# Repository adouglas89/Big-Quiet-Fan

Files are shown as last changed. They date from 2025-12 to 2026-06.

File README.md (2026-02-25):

# Big-Quiet-Fan
This is an axial fan with a blade that is 500 mm diameter (frame is a 550 mm square basically), that has unprecedented flow to noise ratio at pressures useful in air purification appliances, and presumably many other things.  But it's primary application is for making Extra Quiet Corsi-Rosenthal boxes (EQ-CR boxes).  Basically, they get twice the CADR with far less noise than a lasko 3733 fan on low (about 950 CFM CADR with a typical filter set, at 41 dBa noise (400 rpm), so about 9-10 dB less noise).  It's also extremely quite at lower speeds while still getting very good flow, so it's good for a bedroom to prevent allergies, for example.

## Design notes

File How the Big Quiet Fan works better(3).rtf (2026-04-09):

This document is to answer the often asked question of how/why the big quiet fan is so quiet.
● First of all the actual details of curves and polymers are not the whole story
○ The incentives surrounding the project
■ Lack of asshole boss rushing me
■ My own desire to make stuff that’s really really quiet, and do a good job to prove my abilities in this regard. I want it to be beautiful.
■ My reputation in the community and with the funding organization was an important motivating factor I guess.
■ A focus on sheer performance rather than appearance or manufacturability in the early stages. In fact sometimes noise is considered beneficial because people perceive something that’s louder to be more powerful. Obviously dispensing with that kind of pandering to ignorance is an easy way to make progress on performance. I also rejected the idea that it must be cheap. The *ratio* of cost to performance is much more important. In a way both of these and much more comes to making a wise objective function early on and allowing that to guide development efforts. The whole thing is one big optimization effort.
○ The methods I have employed including optimization, actually building prototypes, working with good efficiency are important. Both in terms of getting on with things faster and sooner and also with less money and space. With a fixed budget, higher efficiency will give a better result.
■ Prove the most uncertain stuff first. That was the blades and then the ability to print them with reasonable efficiency. Then the motor/driver comes after. That way if you have to change course you have less lost effort.
■ Obviously basic engineering fundamentals apply, like using modules that others have done a reasonable good job on wherever they are adequate.
○ “Forever modular” is useful, keeping the door open to improvement well after I thought I was done.
○ Keep orderly notes and data, I don’t think paper notes are really up to the challenge. You can’t make a spreadsheet on paper. This is important to remember and refer to what worked best, so you can mix and match the best features during the optimization process. And also if something goes wrong you can figure it out better.

I also spent some time relatively poorly, because I was working towards serial production through additive manufacture. So this whole project did take longer than it would have if I had been able to plan ahead a little more effectively. However to be fair I see supposedly much more experienced people doing very similar things with far lower efficiency. Also exploration is kind of like that, you can’t know what’s ahead, that’s part of the program.

One thing that was profoundly missing was collaborators. That would have helped a lot. Except the funding was in a way a form of collaboration.
This could have been done in some kind of community space, but you’d need some space of your own, and the freedom to run the machines overnight etc. Being able to work in my home was useful on a technical level but I think quite a problem psychologically, as you tend to have problems sleeping and waking when working and sleeping in the same relatively small house (even a full sized house, which I had for a while).

It would be a good idea to also discuss what did not work out as well, some of this will be implied, some included after.

Some people will say this is too much detail, but when you go to make a variant, it’s not going to be too much.

What is the general technique employed here?
● The general idea is to first do the best we can with simulations, then build a test rig and then try various fans with a reasonably intelligent approach (better than brute force) to see which gives the best noise and flow/pressure. To simplify things, I picked one RPM, 300, and optimized to get better results at that point. Now I’m usually using 400 rpm because it’s quiet enough at that speed, so optimizing again for that RPM might yield improvement. Unfortunately this is not actualy that easy as the only practical way to know how much noise one aspect is contributing is by eliminating it. So the motor for instance, you have to make that quiet before you can get far on the blades.
○ The optimization process involved binary searches and also looking in there with smoke etc. to see how the air was flowing around, listening to see if I could determine how the noise was being produced (easy to tell motor hum or blade buzz from the whoosh of the blades due to turbulence for instance). Then forming hypothesis, proving them and testing more.
○ I make at least 52 unique prototypes, I think. Some were not documented as they were uninteresting, like the one with the slightly defective frame that made a surprising amount of noise as a result. By this I mean I often recycled parts to make new fans, including mixing various primaries and secondaries to see what worked better. Different spacings between primary and secondary were also tried but I’m not including that in the total of 52. There must have been hundreds of exact unique combinations tried. The most important thing to document is when progress is made, but documenting everything is probably a good idea, as long as you can still find the good stuff.
○ Obviously, back the best stuff up periodically and keep an orderly workplace etc.
● It’s also useful to note that MERV-13 filters may not be the optimal at these pressures and for these configurations. There may be a significantly better filter/geometrical arrangement combo. You’d have to go back and forth testing and improving both to work your way to a better air purifier if you wanted to optimize for both 400 rpm and different filters. I used 10x merv-13 filters with the VVV in the middle (see bqap builds document).
● A primary blade that is relatively thick. It imparts pressure to the air, and also rotational motion. The pressure is directly useful, the rotational motion will be converted to pressure to some degree by the secondary. Usually it’s just about pressure. The thicker the blade disk (the cylinder around the blades) the better this works, but of course it’s a practical compromise with how large you want to let them be.
● A secondary blade, also called stator blades, which are stationary but the air is rotating relative to them, at a lower rpm however, than the primary relative to the air entering the fan.
● The primary and secondary are curved oppositely to each other, that is the spiral in the xy plane is opposite handedness. This prevents the pressure wave emanating from the primary from slamming into the secondary all of a sudden, which produces a buzzing noise that we don’t want. Many fans use struts that curve for this reason.
○ The struts on some blades are also flat and slanted to reduce their cross section in the direction which the pressure wave propagates. The secondary blades are to some degree like this automatically, although they can’t be minimal cross section of course. But they are a lot better than flat bars.
● The blade number and curves of the primary and secondary are different, the de facto rpm is different so the optimal isn’t likely to be the same.
● Spacing between the primary and secondary turned out to be important. Early prototypes did not work well as the spacing was too large.
● The thin wall on the outer edge of the blades is not strictly that helpful from a noise standpoint, I think, but it is important structurally, allowing the blades to be thinner, and thus easier to print and mold. It also prevents them from flapping around, but to be honest I never tried any variants without it so I don’t know the impact it’s having for sure. People think it reduces tip vortices, but I don’t think that’s likely to be a major factor here, that’s more of an issue at higher blade velocities.
● The spiral curvature (xy plane) and zy plane curvature of the blades,blade number for both the primary and secondary, thickness of the blade disk (thickness of the cylinders that surround the primary and secondary blades), hub diameter had to be adjusted to find something reasonably close to optimal. Diameter was fixed but in another application you might want to optimize that too.
● The grille has to be adequately far away from the primary blades, otherwise it creates noise as the pressure waves slam into it. This is why it’s not directly against the secondary, or integral with the secondary. I found it had to be a separate component, which is unfortunate as it costs more. Of course it can’t be too dense/thick elements as that would impede airflow, too. Making it further away from the primary also reduces the density it has to have, allowing air to flow through it better.
● The polymer turned out to be important. By coincidence I found some fans were quieter than others, and since I kept good notes (this is important, keep orderly notes and data) I was able to identify that it was the polymer used.
● The motor/drive solution is also something that must be done, and once again you’d think there was a good solution for this as a quiet motor is basically just a smooth running motor with sensible electronics, and there are tons of applications for that. Capstan motors, for instance, and indeed motion control in general does not benefit from vibration. Unfortunately once again everyone terminates the effort rather prematurely. Stepper motor drivers for instance, you can get ones that are specifically made to be quiet but they aren’t quiet enough, just because they didn’t do a few things that are needed. I had to do those things, making a new driver. I looked high and low for suitable motors, notably they require an adequate torque to speed ratio in a reasonably efficient operating region without being too expensive. A large motor will have a larger torque to speed ratio of course, but it costs more, it also has higher cogging usually. Cogging and other issues there is some important and useful research on but it’s a lot of work to bake the research into usable modules specific to a given motor.
○ I’m still building the super smooth and quiet motor driver for the stepper motor, but it’s looking promising.
○ With the BLDC motor, there appears to be some kind of vibration source that no change to the drive current/voltage can affect. I suspect it is flexure of the casing/the rotor backing or the stator, or both. The metal simply distorts significantly from the forces involved (any solid will distort at least a bit with any force, just a matter of how much). I am pretty sure almost any torque ripple could be solved by feeding the motor the right waveform. Unless there are some regions where the torque cannot be controlled, but I don’t think that’s the case. Hopefully this won’t happen with the stepper motor. If it does I’ll have to mount the motor in a fancy way to isolate the vibration, or we may have to tolerate a very slight motor buzz.
○ Rubber isolation is easy and important. I used orings under the screw heads etc. in the right places. This helps a lot all else being equal, to mop up that last bit of vibration/noise. They are subject to considerable forces which squishes the rubber and can allow the screw to touch the plastic if the holes are not large enough etc. (3.5 mm drill size is good, not 3.2)

It’s worth noting that it’s probably possible to improve performance slightly further by further adjusting the curves and blade number, thickness of the blade disk, hub diameter etc.I am not immune to the reality which probably led most other fans to not be very good, which is that you have to get on with actually making them at some point, and there is not really that much good reason to exceed the requirements set. That would be ASHRAE 241 for the amount of clean air we need in a classroom and other buildings,and ANSI S12.60, for noise in classrooms (hospital wards and other spaces have similar standards which have mostly similar values anyway). This fan can already be used to make an appliance that can do that with only one fan, while everything else is a long way away from that.

Because things are modular I could change things later to pursue this improvement, if/when there is a good enough reason and funding.

What did not work very well?
● The rings similar to the outermost wall, I had some in the middle regions too, and they added a lot of noise. They did improve the flow/pressure to rpm ratio, though, as predicted by simulations. I noticed from the simulations that the pressure/flow was better in the regions close to these rings, so that is why I added them. That was correct. But the simulation did not show the increased noise.
● I tried using a tpu/nylon blend to increase damping, just for the primary, but it made no difference so I went back to the previous approach. I thought it was going to help as the difference in damping between some rigid filaments did help. It might help for the secondary more, but it’s a little too floppy, it was 72D durometer. 100D might work ok but I couldn’t get any. You can have high damping while still having high stiffness, there is nothing stopping that. It’s just that TPU has good damping and is usually used in elastomers. There are some papers that describe filaments with unusually high damping but you can’t buy the filament of course.

Things I did not try
● Multiple rotors, separated by stators to reduce the rotational velocity of the air. This would increase cost and it actually can get complicated because the bearings can make noises etc. which can be solved but it takes more time and the per unit cost would go up. A single primary and secondary is a reasonable compromise.
● One thing that has some potential is airfoil shaped blades, i.e. the back of the blade has a different curvature than the front. This would be easy to do with printing but it makes the blade thick so with molding you’d end up with heavy blades and using a lot of plastic. Contraction could also be a serious problem. You could try to make it in pieces and assemble them or something. But that’s expensive. For this reason I did not explore airfoil shapes much. I did simulate some and it didn't seem to help much so I didn’t pursue it.
Things that probably don’t matter much
● Some people think the ridges on the sides from the printing must have an impact that is detrimental. I think this is unlikely due to the boundary layer, especially.
● I tried slanting the outer wall a little but it made basically no difference. I may do this again when designing for manufacture as it should make removal from the mold easier.

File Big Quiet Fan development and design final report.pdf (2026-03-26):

# Final report for grant A42, design of the

Big Quiet Fan.

# A fan to greatly outperform the existing fan solutions

for air purifiers.

The project went remarkably well and most of the progress was made in a very short time. Later stages did take longer than I would like, mostly due to waiting on others which tends to be extremely time consuming in the world of manufacturing for some reason.

Extremely good performance has been achieved. Energy efficiency, noise to flow/pressure relationship and even cost of manufacture are all very very good now. Progress was repeatedly made in a less than expected way. Several times I thought I was basically done but was able to make progress on core metrics, notably the CADR to noise ratio when fitted with a typical filter set (about 1000 CFM CADR at 9 pascals of pressure, usually 4 1x25x20 MERV-13 Filtrete filters plus a 20 by 20 by 1 inch one on the bottom of the box, with legs).

I discovered several basic techniques to improve performance of the blades, which can be applied to many other fans in the future:
- Increase the depth of the blades to increase pre-swirl and increase pressure/flow generation of the first blades (what I call the primary blades).
- Use a similar stator (the secondary, I call it), which uses the pre-swirl to boost flow/pressure. This is usually called a straightener, and it does straighten the airflow, but it’s purpose is not actually to do so. I realized it’s basically a fan blade, except the air rotates relative to the blades while the blades stay still.
- Again the stator should be relatively deep
- The curvature of the blades needs to be optimized for any given fan, which I have done here. The optimal in this case appears to be a sort of spiral in the plane perpendicular to the axis of rotation, and a parabolic curve in the other plane.
- The number of blades for both primary and secondary also needs to be optimized, this of course dictates spacing.
- The spirals of the primary and secondary should be of opposite handedness, to eliminate buzzing noise. Buzzing noises can still arise depending on the details of the geometry, I was able to find some combination that practically eliminates any buzz.
- As usual the root of the blades has a different average angle of attack than the tip, usually higher.
- An outermost cylindrical wall allows the blades to be thin and light, and any geometry desired as their stiffness is not a problem. It may help with the turbulence at the tips but

I don’t actually know because it is probably at least harmless and useful to improve the mechanical properties of the blades, so I never tried without it.
- Use a high damping plastic/material for the secondary to reduce noise, this helps a surprising amount.
The process of optimizing the curves and number of blades etc. is basically the hard part. I used simulations but due to the large size of the object and the detail required that didn’t give very good accuracy. The limits of the software I was using were too severe, but certainly it’s fundamentally possible to get better results. In general the software can tell the turbulence energy which should correlate strongly with noise.

One thing that has potential but I did not try much is to change the curvature of the front and back of the blades. In general, I use a thin sheet of material, the curve being the same on both sides. In general an airfoil works better with a different curve on the back than the front, however this would be very heavy and consume more plastic when molded, it also takes far longer to print. I did experiment a bit and it seemed unpromising.

It is probably possible to slightly increase performance by maybe 10 percent, but progress really slowed down and that would be a bit costly. I pretty much hit the budgeted $ on the head so I feel I struck a good compromise.

In general, I measured the pressure inside the filter box while testing a wide range of primaries and secondaries, and each promising combination of the two. I did more than 65 tests of unique combinations. I also poked around visualizing the flow with fog, and hypothesized how promising ways to improve things, combining the best features.

One feature that was promising in simulation but did not help in reality was the use of vertical cylindrical walls that divide up the blades, allowing the blade spacing to be optimized in the different regions. The thing is the blades are moving through the air more slowly in the middle than the edge so it would stand to reason the optimal geometry and spacing would be different there. It also interrupts the undesired radial flow of the air due to centrifugal force. Although this type of feature did improve the rpm to pressure/flow relationship, they increased noise unexpectedly so were dispensed with.

I realized several things:
- Most of the buzzing noise is from the pressure wave hitting the secondary. The opposite handed spirals is the best way to solve this as it also works well in other ways. However optimization of the curves is needed to really polish it off.
- The spacing between the primary and secondary is also very important. In this fan it should be between 3-4 mm. A bit outside that range isn’t a big deal, but it does adversely affect noise/flow/pressure relationship.
- Bearing noise is actually significant and Z4 bearings should be used.

I also found a clever solution for the motor drive system which has many other applications where extremely smooth and quiet motion is desired, especially with a high torque to speed ratio at a low cost:
- The stepper motors were fundamentally promising as they have good torque/speed ratio and are low cost and easy to get. I was actually able to source a hall effect sensor equipped gimbal motor which they say could be supplied for $45 USD, which is highly unusual for such motors of such size and properties, a very good deal. However that came too late and I never even tested it. A suitable stepper is about $8 and the supply is inherently more reliable, so it’s better to use that if you can.
- I knew that sine wave drive tends to work pretty well, audible ring and other noises typically involved with stepper motors can be eliminated, the only remaining vibration would be cogging. The other challenge was commutation while keeping cost low.
- I was able to re-invent synchronous drive basically, almost by accident. It turns out if you just ramp the voltage with RPM that actually works great to drive the motor, the current and torque is automatically regulated within a fairly wide range due to the way the back emf changes with the so called torque angle (when the motor is loaded more, back emf goes down allowing more current, increasing torque to match the load).
- However I found the system oscillated too much, leading to step loss. I was able to solve this with damping using TPU, a flywheel made of TPU with enough bolts around it’s periphery for mass was sufficient.
- The last bit of vibration was dealt with by isolation, using a flexible coupler. It was difficult to deal with the creep set etc. however I was able to find a solution.
- The noise from even the Z4 bearings (quietest you can get) had to be isolated with a small hard TPU cushion (72D) around the bearings, but this is cheap and works well.

Unfortunately this whole system does imply increased costs over a bare stepper motor directly driving the blades, but not much, just some plastic and rubber parts and a couple bearings, and the shaft. The parts can all be printed or molded easily.

I did not try multiple rotors, perhaps on the same shaft. That has potential, it increases size but could be sensible. That would be the next major pattern to employ to further increase the noise/cadr ratio, I think. However it increases size and complexity and thus cost. This system is quite close to any ordinary fan, in its simplicity,and I think it’s rare you would have a compelling need for better CADR/noise ratio. You can always just use twice as many air purifiers, in a pinch. I think this is a good compromise.

Driving the fan blades with the motor directly does actually work, the vibrations are damped enough, but you get a buzzing noise. I tried quite extensively to eliminate this buzzing noise through firmware optimization. Theoretically I thought the cogging could be eliminated by superimposing the waveform 180 degrees out of phase, causing a torque ripple that cancels out the cogging or other torque ripple. I built a system that was able to measure torque ripple normatively and used a global optimizer to adjust the waveform, searching for any waveform that would help and improving on it. The system was good, if I imposed a torque ripple it was able to quickly find the right waveform to cancel it out, however for some reason that I still do not understand it was never able to make meaningful reductions in the torque ripple that the stepper motor exhibited with pure sine wave drive. It may be that there were oscillations in the electrical-mechanical system combined which were dynamic in origin. However I did actually test for this by putting damping in in the electrical line and it didn’t seem like it. It’s possible a damping flywheel on the back of a dual shaft stepper with the blades directly mounted to the motor would work, but I don’t think so. I tried a rubber coupler on the blades which should have a similar effect and it hardly helped.

I have designed a drive system PCB which is applicable to other applications and can easily be reprogrammed. It uses relatively common and low cost parts. It is fairly refined, I got the pro layout service and have gone through several prototypes. Extra pins are broken out for auxiliary use etc. The Arduino program is also of course published and can be adapted to other scenarios.

Budget:
Total budget was $50,000 USD for the design and development, including all materials, equipment, premises and labor. Most of this was expended and the remainder has been woven into future grants.
| cad | usd
labor rate | 35
| CAD | USD
labor cost | 44800 | 32463.76812
Parts/equipment /materials | 15831 | 11471.73913
premises | 1800 | 1304.347826
With labor | 62431 | 45239.85507

Estimated impact
This part of the road has now been well paved for far superior noise/cadr ratio air purifiers for
millions or even billions of people around the globe. To have not undertaken such a research project would have been absurd, given the number of fans and air purifiers that are needed across the globe in the coming years.

I would argue it is a bit wacky to only have one person on a relatively tight budget doing this, given the apparent potential. It would be great to build a simulation system and really make something completely optimal. However I would be surprised if that led to even a 10% improvement in CADR to noise ratio.

This fan as it stands really is pretty good. I can turn it up to 400 rpm (1030 cfm CADR measured) and work in my apartment right next to it without irritation, in fact the sheer amount it moves around, causing quite a draft is the most annoying part of leaving it on like that. If I turn it down it is inaudible at normal distances even with 36 dBa background noise, allowing tremendous CADR while sleeping.

The techniques could also be applied to other smaller format air purifiers. There are companies that make 250 mm PC fans for instance, it would be a good idea to use these tricks in that context, especially combined with their low cost approach to the motor.

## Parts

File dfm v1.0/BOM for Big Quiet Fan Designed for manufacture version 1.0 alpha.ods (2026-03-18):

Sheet: bom
group | part or material | sub group | specs | number | cost each CAD | cost each USD | labor minutes | total cost | grams plastic (estimate) | mold or tooling cost | notes | supplier
high damping plastic parts | secondary/frame |  |  | 1 |  | 9.5 |  | 9.5 | 1300
 | primary |  |  | 1 |  | 7 |  | 7 | 750
 | grille |  |  | 1 |  | 4 |  | 4 | 300
 |  |  |  |  |  |  |  | 0
any hard plastic parts |  |  |  |  |  |  |  | 0
 | electronics cover |  |  | 1 |  | 2 |  | 2 | 90
 | motor mount |  |  | 1 |  | 3 |  | 3 | 300
 | shaft clamp |  |  | 1 |  | 2 |  | 2
 | motor cover |  |  | 1 |  | 1.5 |  | 1.5
Shore 95A TPU |  |  |  |  |  |  |  | 0
 | Motor mount flexure |  |  | 1 |  | 2.5 |  | 2.5
 | flywheel |  |  | 1 |  | 2 |  | 2
 | bearing cushion |  |  | 2 |  | 0.25 |  | 0.5
 | shaft spacer motor side |  |  | 1 |  | 0.25 |  | 0.25
 | shaft spacer blade side |  |  | 1 |  | 0.25 |  | 0.25 |  |  | haven't tried it with 95 A yet, I used 72D in prototyping, any hard plastic is probably fine actualy but need to test it, even small squeaking sounds can be a problem.
Shore 85A TPU |  |  |  |  |  |  |  | 0
 | coupler rubber part |  |  | 1 |  | 0.4 |  | 0.4
rubber |  |  |  |  |  |  |  | 0
 | orings are used in the prototypes to compensate for poor perpendicularity, this should not be needed in mass production. |  |  |  |  |  |  | 0 |  |  | Not clear yet if orings on the shaft clamp to primary interface are beneficial for isolating bearing noise, experiment needed. Probably not.
electronics/electrical |  |  |  |  |  |  |  | 0
 | electronics board/driver |  | 2 phase stepper driver, sine wave, with voltage ramping, stall/overload detection, motion detect on startup, acceleration, serial interface, pwm in and tach out | 1 |  | 16 |  | 16
 | power supply |  | 24 volt 2 amp, ul listed, with integral short circuit/overcurrent protection, 5.5 mm jack barrel ground I think | 1 |  | 6 |  | 6
 | 6 pin 3.81 mm pitch 2edgk connector, pluggable,male |  |  | 1 |  | 1 |  | 1 |  |  | for motor wires to board interface
 | thermal fuse |  | trips at 72 degrees C is good. 4 amps min. | 1 |  | 1 |  | 1
 | wire for thermal fuse |  | should be red to indicate positive power side | 1 |  | 1.5 |  | 1.5
screws |  |  |  |  |  |  |  | 0
 | M3 self tapping 12 mm long 2.5 mm hex socket head | For motor flexure mounting | alloy (black finish is fine) | 8 |  | 0.05 |  | 0.4
 |  | for grille mounting | alloy (black finish is fine) | 8 |  | 0.05 |  | 0.4
 | M3 8 mm self tapping screws 2.5 mm head | for primary to shaft clamp interface |  | 3 |  | 0.05 |  | 0.15
 | M3 self tapping 20 mm screws , 2.5 mm hex socket head | for motor mount to secondary interface |  | 3 |  | 0.05 |  | 0.15
 | M3 8 mm self tapping screws 2.5 mm head | electronics cover screws |  |  |  | 0.05 |  | 0
 | M2 self tapping screws 8 mm long, hex socket head 1.5 mm socket | for mounting electronic board | alloy (black finish is fine) | 4 |  | 0.05 |  | 0.2
 | M5 bolts for shaft clamp (lenght?) Hex socket |  | stainless or alloy, regular thread | 2 |  | 0.3 |  | 0.6
 | M5 nuts |  | stainless or alloy regular thread | 2 |  | 0.15 |  | 0.3
other |  |  |  |  |  |  |  | 0
 | shaft |  | 68 mm long is ideal, 70 is fine. | 1 |  | 2 |  | 2
 | shaft retention clamp |  | 8 mm id shaft clamp to ensure the primary cannot slowly slide off if friction is not adequate at high power. | 1 |  | 3 |  | 3 |  |  | this is probably optional and could be omitted, if so the shaft can be reduced in lenght by about 10 mm
 | bearings 8 mm ID OD? Thickness? |  | Should be Z4 noise at least I think that's what I have, the precision I forget but I'm pretty sure the ones I have are actually P6. So top notch bearings on both counts basically | 2 |  | 0.25 |  | 0.5 |  |  | no idea what abec that is.
 | Motor |  | Nema 23 2Nm or more, some make more vibrational noise than others, it has to be one of the quiet ones | 1 |  | 11 |  | 11 |  |  | rattmotor ones worked but have a high defect rate. The only one I know for sure that works right now is model number 23Hs8430B 3A, which is a dual shaft model so not ideal.
 | 3 jaw spider coupler |  | should be a 3 jaw one, you have to watch. 8 mm ID. | 1 |  | 3 |  | 3
assembly jigs and tools and mateials |  |  |  |  |  |  |  | 0
 | motor flexure positioning jig |  |  |  |  |  |  | 0 |  |  | simple printed object to position the motor mount flexure on the motor in the ideal spot easily
 | screw drivers |  |  |  |  |  |  | 0
 | E6000 glue |  |  | 1 |  | 0.1 |  | 0.1 |  |  | to glue the moto rmount flexure to the motor, this is optional but probably advisable.
total |  |  |  |  |  |  |  | 82.2

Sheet: labor and other costs
 | assembly process actions |  | labor minutes | notes
per unit
 | cut wire for thermal fuse |  | 1
 | solder wire to thermal fuse (be very careful not to overheat it), test it to ensure not broken by soldering, then glue to the motor ith e6000. Should go on back of motor to not interfere with flexure |  | 2 | might need to attach heatsink (spring loaded pliers basically/latching pliers)
 | put flexure on motor inright position and glue flexure to motor |  | 2
 | put bolts on flywheel |  | 3
 | add clamp bolt to flywheel |  | 1
 | put flywheel on motor |  | 1
 | attach spider coupler motor side |  | 0.5
 | attach spider coupler shaft side |  | 0.5
 | add shaft spacer to shafr behind spider coupler |  | 0.5
 | add rubber peice to spider coupler |  | 1
 | add bearing cushions and bearings to motor mount |  | 1
 | insert motor/flywheel/shaft assembly into motor mount |  | 1
 | install motor mount in secondary |  | 2
 | attach shaft clamp to primary |  | 1
 | put bolts and nuts on shaft clamp |  | 0.5
 | put shaft spacer on shaft |  | 0.5
 | connect shaft clamp/primary to shaft, press slightly to ensure no axial play |  | 1
 | add shaft clamp to ensure retention. |  | 0.5
 | add electronics board |  | 1
 | wire the connector for the motor-board connection |  | 4
 | test it |  | 10
 | any corrections. Noise must be acceptable. For early units, check stall detection is working |  | 5
 | add the electronics cover |  | 1
 | add motor cover on back |  | 1
 | packaging |  | 10
 | coordination, management, restocking etc. |  | 5
 | total labor minutes |  | 57
 | labor rate usd per hour | 25
 | cost for labor |  | 23.75
 | premises |  | 4
 | electricity, other random stuff |  | 2
 | sum of all labor, parts and costs. |  | 111.95

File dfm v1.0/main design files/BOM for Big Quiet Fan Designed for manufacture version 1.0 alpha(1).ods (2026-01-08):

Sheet: bom
group | part or material | sub group | specs | number | cost each CAD | cost each cad | labor minutes | line cost USD | grams plastic (estimate) | mold or tooling cost | notes | supplier
high damping plastic parts | secondary/frame |  |  | 1 |  | 11 |  | 11 | 1300 |  | includes shipping
 | primary |  |  | 1 |  | 10 |  | 10 | 750 |  | includes shipping
 | grille |  |  | 1 |  | 5 |  | 5 | 300 |  | includes shipping
any hard plastic parts, probably print farmed
 | electronics cover |  |  | 1 |  | 3 |  | 3 | 90
 | motor mount |  |  | 1 |  | 4 |  | 4 | 300
 | shaft clamp |  |  | 1 |  | 2 |  | 2
 | motor cover |  |  | 1 |  | 2 |  | 2
Shore 95A TPU
 | coupler blade side |  |  |  |  | 2
 | flywheel |  |  | 1 |  | 2 |  | 2
 | bearing cushion |  |  | 2 |  | 0.25 |  | 0.5 |  |  | might want harder tpu to reduce sag, try it
 | shaft spacer motor side |  |  | 1 |  | 0.25 |  | 0.25 |  |  | might want harde tpu
 | shaft spacer blade side |  |  | 1 |  | 0.25 |  | 0.25 |  |  | might want harde tpu
Shore 85A TPU
 | Motor mount flexure |  |  | 1 |  | 2.5 |  | 2.5
rubber
 | orings are used in the prototypes to compensate for poor perpendicularity, may be able to eliminate this with adjustment, the process of manually adjusting things is also a pain so that would be good |  |  | 3 |  | 0.05 |  | 0.15
 | same orings are used on the rubber coupler in two areas |  |  | 2 |  | 0.05 |  | 0.1
electronics/electrical
 | electronics board/driver |  | 2 phase stepper driver, sine wave, with voltage ramping, stall/overload detection, motion detect on startup, acceleration, serial interface, pwm in and tach out | 1 |  | 16 |  | 16
 | power supply |  | 24 volt 2 amp, ul listed, with integral short circuit/overcurrent protection, 5.5 mm jack barrel ground I think | 1 |  | 6 |  | 6
 | 6 pin 3.81 mm pitch 2edgk connector, pluggable,male |  |  | 1 |  | 1 |  | 1 |  |  | for motor wires to board interface
 | thermal fuse |  | trips at 72 degrees C is good. 4 amps min. | 1 |  | 1 |  | 1
 | wire for thermal fuse |  | should be red or yellow to indicate positive power side | 1 |  | 1.5 |  | 1.5
 | any additional wire needed, usually to extend the stepper motor wires |  |  |  |  |  |  | 1
screws
 | M3 self tapping 8 mm long 2.5 mm hex socket head | For motor flexure mounting | alloy (black finish is fine) | 8 |  | 0.05 |  | 0.4
 | 8x M3 12 mm screws | for grille mounting | alloy (black finish is fine) | 8 |  | 0.05 |  | 0.4
 | M3 8 mm self tapping screws 2.5 mm head | for primary to shaft clamp interface |  | 3 |  | 0.05 |  | 0.15
 | M3 self tapping 20 mm screws , 2.5 mm hex socket head | for motor mount to secondary interface |  | 3 |  | 0.05 |  | 0.15
 | M3 self tapping 20 mm screws , 2.5 mm hex socket head | for motor cover |  | 4 |  | 0.05 |  | 0.2
 | M3 8 mm self tapping screws 2.5 mm head | electronics cover screws |  | 3 |  | 0.05 |  | 0.15
 | M2 self tapping screws 8 mm long, hex socket head 1.5 mm socket | for mounting electronic board | alloy (black finish is fine) | 4 |  | 0.05 |  | 0.2
 | M6 bolts for flywheel |  | alloy (black finish is fine) 10 mm length | 10 |  | 0.5 |  | 5 |  |  | I don't know why they are so expensive but they are.
 | m6 nuts for flywheel |  |  | 10 |  | 0.1 |  | 1
 | M6 bolts for the motor side flywheel clamp |  | M6 30 mm IIRC, check length again. | 2 |  | 0.05 |  | 0.1
 | M6 nuts |  |  | 2 |  | 0.05 |  | 0.1
 | M4 bolts for the bladeside shaft coupler |  | alloy (black) 30 mm IIRC, check that | 2 |  | 0.05 |  | 0.1
 | M4 nuts |  |  | 2 |  | 0.05 |  | 0.1
 | M4 washers |  |  | 4 |  | 0.05 |  | 0.2
 | M5 bolts for shaft clamp (lenght?) Hex socket |  | stainless or alloy, regular thread | 2 |  | 0.3 |  | 0.6
 | M5 nuts |  | stainless or alloy regular thread | 2 |  | 0.15 |  | 0.3
other |  |  |  |  |  |  |  | 0
 | shaft |  | 68 mm long is ideal, 70 is fine. 8 mm od, shaft tolerance of couse | 1 |  | 2 |  | 2
 | bearings 8 mm ID OD? Thickness? |  | Should be Z4 noise at least I think that's what I have, the precision I forget but I'm pretty sure the ones I have are actually P6. So top notch bearings on both counts basically | 2 |  | 0.25 |  | 0.5 |  |  | no idea what abec that is. We might want to up the outer diameter and thickness, the ID is good as is though.
 | Motor |  | Nema 23 2Nm or more, some make more vibrational noise than others, it has to be one of the quiet ones | 1 |  | 13 |  | 13 |  |  | rattmotor ones worked but have a high defect rate. The only one I know for sure that works right now is model number 23Hs8430B 3A, which is a dual shaft model so not ideal.
 | 4 jaw spider coupler |  | should be a 4 jaw one, you have to watch. 8 mm ID. 25 mm od. what was the overall length again? | 0.5 |  | 3 |  | 1.5 |  |  | that's 2 prongs per half. We only use half of one.
assembly jigs and tools and mateials |  |  |  |  |  |  |  | 0
 | motor flexure positioning jig |  |  |  |  |  |  | 0 |  |  | simple printed object to position the motor mount flexure on the motor in the ideal spot easily
 | screw drivers |  |  |  |  |  |  | 0
 | E6000 glue |  |  | 1 |  | 0.1 |  | 0.1 |  |  | to glue the moto rmount flexure to the motor, this is optional but probably advisable.
 | solder
total |  |  |  |  |  |  |  | 95.5

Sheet: labor and other costs
 | assembly process actions |  | labor minutes | notes
per unit
 | cut wire for thermal fuse |  | 1
 | solder wire to thermal fuse (be very careful not to overheat it), test it to ensure not broken by soldering, then glue to the motor ith e6000. Should go on back of motor to not interfere with flexure |  | 2 | might need to attach heatsink (spring loaded pliers basically/latching pliers)
 | put flexure on motor inright position and glue flexure to motor |  | 2
 | put bolts on flywheel |  | 3
 | add clamp bolt to flywheel |  | 1
 | put flywheel on motor |  | 1
 | attach spider coupler motor side |  | 0.5
 | add shaft spacer to shafr behind spider coupler |  | 0.5
 | add rubber peice to spider coupler |  | 1
 | add bearing cushions and bearings to motor mount |  | 1
 | insert motor/flywheel/shaft assembly into motor mount |  | 1
 | install motor mount in secondary |  | 2
 | attach shaft clamp to primary |  | 1
 | put bolts and nuts on shaft clamp |  | 0.5
 | put shaft spacer on shaft |  | 0.5
 | connect shaft clamp/primary to shaft, press slightly to ensure no axial play |  | 1
 | add shaft clamp to ensure retention. |  | 0.5
 | add electronics board |  | 1
 | wire the connector for the motor-board connection |  | 4
 | test it |  | 5
 | any corrections. Noise must be acceptable. For early units, check stall detection is working |  | 5
 | add the electronics cover |  | 1
 | add motor cover on back |  | 1
 | packaging |  | 10
 | coordination, management, restocking etc. |  | 5
printing
 | all printing |  | 15
 | post processing |  | 10
 | total labor minutes |  | 76.5
 | labor rate cad per hour | 25
 | cost for labor |  | 31.875
 | premises |  | 4
 | electricity, other random stuff |  | 2
 | sum of all labor, parts and costs. cad |  | 133.375

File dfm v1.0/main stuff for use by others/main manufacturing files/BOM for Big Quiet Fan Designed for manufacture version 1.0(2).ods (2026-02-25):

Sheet: bom fully moldable
group | part or material | sub group | other specs | number | cost each cad | labor minutes | line cost cad | usd | grams plastic (estimate) | mold or tooling cost | notes | supplier | part number
high damping plastic parts | secondary/frame |  |  | 1 | 7 |  | 7 |  | 1300 |  | includes shipping | molded by injection molder, who is not clear yet
 | primary |  |  | 1 | 7 |  | 7 |  | 750 |  | includes shipping | molded by injection molder, who is not clear yet
 | grille |  |  | 1 | 5 |  | 5 |  | 300 |  | includes shipping | molded by injection molder, who is not clear yet
any hard plastic parts, probably print farmed
 | electronics cover |  |  | 1 | 1 |  | 1 |  | 90 |  |  | molded by injection molder, who is not clear yet
 | motor mount |  |  | 1 | 1 |  | 1 |  | 300 |  |  | molded by injection molder, who is not clear yet
 | motor cover |  |  | 1 | 1 |  | 1 |  |  |  |  | molded by injection molder, who is not clear yet
Shore 95A TPU
 | coupler blade side |  |  | 1 | 1 |  | 1 |  |  |  |  | molded by injection molder, who is not clear yet
 | flywheel |  |  | 1 | 1 |  | 1 |  |  |  |  | molded by injection molder, who is not clear yet
 | shaft spacer motor side |  |  | 1 | 0.1 |  | 0.1 |  |  |  | might want harde tpu | molded by injection molder, who is not clear yet
 | shaft spacer blade side |  |  | 2 | 0.1 |  | 0.2 |  |  |  | might want harde tpu | molded by injection molder, who is not clear yet
shore 72D TPU
 | bearing cushion |  |  | 2 | 0.1 |  | 0.2 |  |  |  | might want harder tpu to reduce sag, try it | molded by injection molder, who is not clear yet
Shore 85A TPU
 | Motor mount flexure |  |  | 1 | 1 |  | 1 |  |  |  |  | molded by injection molder, who is not clear yet
other rubber
 | orings are used in the prototypes to compensate for poor perpendicularity, may be able to eliminate this with adjustment, the process of manually adjusting things is also a pain so that would be good |  |  | 3 | 0.05 |  | 0.15 |  |  |  |  | any
 | same orings are used on the rubber coupler under the arms, this may be optional |  |  | 2 | 0.05 |  | 0.1 |  |  |  |  | any
electronics/electrical
 | electronics board/driver |  | 2 phase stepper driver, sine wave, with voltage ramping, stall/overload/miswiring detection, motion detect on startup, acceleration, serial interface, pwm in and tach out | 1 | 20 |  | 20 |  |  |  |  | custom board, jlcbpcb works fine
 | power supply |  | 24 volt 2 amp, ul listed, with integral short circuit/overcurrent protection, 5.5 mm jack barrel ground I think | 1 | 6 |  | 6 |  |  |  |  | any
 | 6 pin 3.81 mm pitch 2edgk connector, pluggable,male |  |  | 1 | 1 |  | 1 |  |  |  | for motor wires to board interface
 | thermal fuse |  | trips at 72 degrees C is good. 4 amps min. this one is good for 10 amp | 1 | 1 |  | 1 |  |  |  | I don't think we really need the thermal fuse but let's include it for now for redundant safety | Cantherm is the manufacturer, digikey sells it | SDF DF077S
 | wire for thermal fuse |  | should be red or yellow to indicate positive power side | 1 | 1.5 |  | 1.5 |  |  |  |  | any
 | knob for potentiometer |  |  | 1 | 0.2 |  | 0.2 |  |  |  |  | any
 | power supply pigtail |  | 30 long is good, 5.5 mm jack | 1 | 2 |  | 2 |  |  |  |  | any
screws
 | M3 self tapping 8 mm long 2.5 mm hex socket head | For motor flexure mounting | alloy (black finish is fine) | 8 | 0.05 |  | 0.4 |  |  |  |  | any
 | 8x M3 12 mm screws | for grille mounting | alloy (black finish is fine) | 8 | 0.05 |  | 0.4 |  |  |  |  | any
 | M3 8 mm self tapping screws 2.5 mm head | for primary to shaft clamp interface |  | 3 | 0.05 |  | 0.15 |  |  |  |  | any
 |  | for output grille |  | 8 | 0.05 |  | 0.4 |  |  |  |  | any
 | M3 8 mm self tapping flat end screws | for intake grille |  | 8 | 0.05 |  | 0.4 |  |  |  |  | any
 | M3 self tapping 20 mm screws , 2.5 mm hex socket head | for motor mount to secondary interface |  | 3 | 0.05 |  | 0.15 |  |  |  |  | any
 | M3 self tapping 20 mm screws , 2.5 mm hex socket head | for motor cover |  | 4 | 0.05 |  | 0.2 |  |  |  |  | any
 | M3 8 mm self tapping screws 2.5 mm head | electronics cover screws |  | 3 | 0.05 |  | 0.15 |  |  |  |  | any
 | M2 self tapping screws 8 mm long, hex socket head 1.5 mm socket | for mounting electronic board | alloy (black finish is fine) | 3 | 0.05 |  | 0.15 |  |  |  |  | any
 | M6 bolts for flywheel |  | alloy (black finish is fine) 10 mm length | 8 | 0.5 |  | 4 |  |  |  | I don't know why they are so expensive but they are. | any
 | m6 nuts for flywheel |  | alloy (black finish is fine) | 8 | 0.1 |  | 0.8 |  |  |  |  | any
 | M6 bolts for the motor side flywheel clamp |  | M6 30 mm IIRC, check length again. | 2 | 0.05 |  | 0.1 |  |  |  |  | any
 | M6 nuts |  |  | 2 | 0.05 |  | 0.1 |  |  |  |  | any
 | M5 bolts for shaft clamp 30 mm long Hex socket |  | stainless or alloy, regular thread | 2 | 0.3 |  | 0.6 |  |  |  |  | any
 | M5 nuts |  | stainless or alloy regular thread | 2 | 0.15 |  | 0.3 |  |  |  |  | any
other |  |  |  |  |  |  | 0
 | shaft |  | 68 mm long is ideal, 70 is fine. 8 mm od, shaft tolerance of couse | 1 | 2 |  | 2 |  |  |  |  | any
 | bearings 8 mm ID, 12 mm OD, 3.5 mm thick (8x12x3.5) |  | Z4 noise rating, P6 precision level. Confirmed that's what I have. | 2 | 0.25 |  | 0.5 |  |  |  | no idea what abec that is. We might want to up the outer diameter and thickness, the ID is good as is though. | Shenzhen Wanyuan Bearing Co., Ltd. | MR128ZZ
 | Motor |  | Nema 23 2Nm or more, some make more vibrational noise than others, it has to be one of the quiet ones. Wire lead length has to be greater than 48 cm. just make it 50 probably that's good. The usual of 25 or so is too short. | 1 | 13 |  | 13 |  |  |  | rattmotor ones worked but have a high defect rate. The only one I know for sure that works right now is model number 23Hs8430B 3A, which is a dual shaft model so not ideal. | Changzhou Zhongzhi Electric Motor & Electric Appliance Co., Ltd. (says zz-motor.com on the label) | 57HS843004A-001
 | 4 jaw spider coupler *half* |  | should be a 4 jaw one, you have to watch. 8 mm ID. 25 mm od. 25 mm overall length | 0.5 | 3 |  | 1.5 |  |  |  | that's 2 prongs/jaws per half. We only use half of one. The ones in a pair are a mirror of each other, you need a different capture thing for the other of the mirrored pair. to hold the coupler onto the spider coupler half, or you can't reach to do up the clamp screw | any
 | wavy/belleville washer |  | M8 carbon steel or stainless steel, I used carbon steel in prototyping | 1 | 0.2 |  | 0.2 |  |  |  | to keep tension on the bearings despite creep | any
assembly jigs and tools and mateials
 | motor flexure positioning jig |  |  |  |  |  | 0 |  |  |  | simple printed object to position the motor mount flexure on the motor in the ideal spot easily | printed
 | screw drivers |  |  |  |  |  | 0 |  |  |  |  | any
 | E6000 glue |  |  | 1 | 0.1 |  | 0.1 |  |  |  | to glue the moto rmount flexure to the motor, this is optional but probably advisable. Also to glue the thermal fuse to the motor | any
 | solder |  | lead free, must be compatible alloy of course. |  |  |  |  |  |  |  | Probably will have to solder the pigtail to the board. | any
total |  |  |  |  |  |  | 83.05 | 60.18115942

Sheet: bom printable
group | part or material | sub group | other specs | number | cost each CAD | cost each cad | labor minutes | line cost cad | usd | grams plastic (estimate) | mold or tooling cost | notes | supplier | part number
high damping plastic parts | secondary/frame |  |  | 1 |  | 11 |  | 7 |  | 1300 |  | includes shipping | molded
 | primary |  |  | 1 |  | 10 |  | 7 |  | 750 |  | includes shipping | molded
 | grille |  |  | 1 |  | 5 |  | 5 |  | 300 |  | includes shipping | molded
any hard plastic parts, probably print farmed
 | electronics cover |  |  | 1 |  | 4 |  | 4 |  | 90
 | motor mount |  |  | 1 |  | 4 |  | 4 |  | 300
 | motor cover |  |  | 1 |  | 4 |  | 4
Shore 95A TPU
 | coupler blade side |  |  | 1 |  | 2 |  | 2
 | flywheel |  |  | 1 |  | 2 |  | 2
 | shaft spacer motor side |  |  | 1 |  | 0.1 |  | 0.1 |  |  |  | might want harde tpu
 | shaft spacer blade side |  |  | 2 |  | 0.1 |  | 0.2 |  |  |  | might want harde tpu
shore 72D TPU
 | bearing cushion |  |  | 2 |  | 0.1 |  | 0.2 |  |  |  | might want harder tpu to reduce sag, try it
Shore 85A TPU
 | Motor mount flexure |  |  | 1 |  | 2.5 |  | 2.5
other rubber
 | orings are used in the prototypes to compensate for poor perpendicularity, may be able to eliminate this with adjustment, the process of manually adjusting things is also a pain so that would be good |  |  | 3 |  | 0.05 |  | 0.15 |  |  |  |  | any
 | same orings are used on the rubber coupler under the arms, this may be optional |  |  | 2 |  | 0.05 |  | 0.1 |  |  |  |  | any
electronics/electrical
 | electronics board/driver |  | 2 phase stepper driver, sine wave, with voltage ramping, stall/overload detection, motion detect on startup, acceleration, serial interface, pwm in and tach out | 1 |  | 20 |  | 20 |  |  |  |  | custom board, jlcbpcb works fine
 | power supply |  | 24 volt 2 amp, ul listed, with integral short circuit/overcurrent protection, 5.5 mm jack barrel ground I think | 1 |  | 6 |  | 6 |  |  |  |  | any
 | 6 pin 3.81 mm pitch 2edgk connector, pluggable,male |  |  | 1 |  | 1 |  | 1 |  |  |  | for motor wires to board interface
 | thermal fuse |  | trips at 72 degrees C is good. 4 amps min. this one is good for 10 amp | 1 |  | 1 |  | 1 |  |  |  | I don't think we really need the thermal fuse but let's include it for now for redundant safety | Cantherm is the manufacturer, digikey sells it | SDF DF077S
 | wire for thermal fuse |  | should be red or yellow to indicate positive power side | 1 |  | 1.5 |  | 1.5 |  |  |  |  | any
 | knob for potentiometer |  |  | 1 |  | 0.2 |  | 0.2 |  |  |  |  | any
 | power supply pigtail |  |  | 1 |  | 2 |  | 2 |  |  |  |  | any
screws
 | M3 self tapping 8 mm long 2.5 mm hex socket head | For motor flexure mounting | alloy (black finish is fine) | 8 |  | 0.05 |  | 0.4 |  |  |  |  | any
 | 8x M3 12 mm screws | for grille mounting | alloy (black finish is fine) | 8 |  | 0.05 |  | 0.4 |  |  |  |  | any
 | M3 8 mm self tapping screws 2.5 mm head | for primary to shaft clamp interface |  | 3 |  | 0.05 |  | 0.15 |  |  |  |  | any
 |  | for output grille |  | 8 |  | 0.05 |  | 0.4 |  |  |  |  | any
 | M3 8 mm self tapping flat end screws | for intake grille |  | 8 |  | 0.05 |  | 0.4 |  |  |  |  | any
 | M3 self tapping 20 mm screws , 2.5 mm hex socket head | for motor mount to secondary interface |  | 3 |  | 0.05 |  | 0.15 |  |  |  |  | any
 | M3 self tapping 20 mm screws , 2.5 mm hex socket head | for motor cover |  | 4 |  | 0.05 |  | 0.2 |  |  |  |  | any
 | M3 8 mm self tapping screws 2.5 mm head | electronics cover screws |  | 3 |  | 0.05 |  | 0.15 |  |  |  |  | any
 | M2 self tapping screws 8 mm long, hex socket head 1.5 mm socket | for mounting electronic board | alloy (black finish is fine) | 3 |  | 0.05 |  | 0.15 |  |  |  |  | any
 | M6 bolts for flywheel |  | alloy (black finish is fine) 10 mm length | 8 |  | 0.5 |  | 4 |  |  |  | I don't know why they are so expensive but they are. | any
 | m6 nuts for flywheel |  | alloy (black finish is fine) | 8 |  | 0.1 |  | 0.8 |  |  |  |  | any
 | M6 bolts for the motor side flywheel clamp |  | M6 30 mm IIRC, check length again. | 2 |  | 0.05 |  | 0.1 |  |  |  |  | any
 | M6 nuts |  |  | 2 |  | 0.05 |  | 0.1 |  |  |  |  | any
 | M5 bolts for shaft clamp 30 mm long Hex socket |  | stainless or alloy, regular thread | 2 |  | 0.3 |  | 0.6 |  |  |  |  | any
 | M5 nuts |  | stainless or alloy regular thread | 2 |  | 0.15 |  | 0.3 |  |  |  |  | any
other |  |  |  |  |  |  |  | 0
 | shaft |  | 68 mm long is ideal, 70 is fine. 8 mm od, shaft tolerance of couse | 1 |  | 2 |  | 2 |  |  |  |  | any
 | bearings 8 mm ID, 12 mm OD, 3.5 mm thick (8x12x3.5) |  | Z4 noise rating, P6 precision level. Confirmed that's what I have. Might seem like overkill but it's not really. | 2 |  | 0.25 |  | 0.5 |  |  |  | no idea what abec that is. We might want to up the outer diameter and thickness, the ID is good as is though. | Shenzhen Wanyuan Bearing Co., Ltd. | MR128ZZ
 | Motor |  | Nema 23 2Nm or more, some make more vibrational noise than others, it has to be one of the quiet ones. Wire lead length has to be greater than 48 cm. just make it 50 probably that's good. The usual of 25 or so is too short. | 1 |  | 13 |  | 13 |  |  |  | rattmotor ones worked but have a high defect rate. The only one I know for sure that works right now is model number 23Hs8430B 3A, which is a dual shaft model so not ideal. | Changzhou Zhongzhi Electric Motor & Electric Appliance Co., Ltd. (says zz-motor.com on the label) | 57HS843004A-001
 | 4 jaw spider coupler *half* |  | should be a 4 jaw one, you have to watch. 8 mm ID. 25 mm od. 25 mm overall length | 0.5 |  | 3 |  | 1.5 |  |  |  | that's 2 prongs/jaws per half. We only use half of one. The ones in a pair are a mirror of each other, you need a different capture thing for the other of the mirrored pair. to hold the coupler onto the spider coupler half, or you can't reach to do up the clamp screw | any
 | wavy/belleville washer |  | M8 carbon steel or stainless steel, I used carbon steel in prototyping | 1 |  | 0.2 |  | 0.2 |  |  |  | to keep tension on the bearings despite creep | any
assembly jigs and tools and mateials |  |  |  |  |  |  |  | 0
 | motor flexure positioning jig |  |  |  |  |  |  | 0 |  |  |  | simple printed object to position the motor mount flexure on the motor in the ideal spot easily | printed
 | screw drivers |  |  |  |  |  |  | 0 |  |  |  |  | any
 | E6000 glue |  |  | 1 |  | 0.1 |  | 0.1 |  |  |  | to glue the moto rmount flexure to the motor, this is optional but probably advisable. Also to glue the thermal fuse to the motor | any
 | solder |  | lead free, must be compatible alloy of course. |  |  |  |  |  |  |  |  | Probably will have to solder the pigtail to the board. | any, weller is good
total |  |  |  |  |  |  |  | 95.55 | 69.23913043

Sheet: labor and other costs
 | assembly process actions |  | labor minutes | notes
per unit
 | cut wire for thermal fuse |  | 1
 | solder wire to thermal fuse (be very careful not to overheat it), test it to ensure not broken by soldering, then glue to the motor ith e6000. Should go on back of motor to not interfere with flexure |  | 2 | might need to attach heatsink (spring loaded pliers basically/latching pliers)
 | put flexure on motor inright position and glue flexure to motor |  | 2
 | put bolts on flywheel |  | 3
 | add clamp bolt to flywheel |  | 1
 | put flywheel on motor |  | 1
 | attach spider coupler motor side |  | 0.5
 | add shaft spacer to shafr behind spider coupler |  | 0.5
 | add rubber peice to spider coupler |  | 1
 | add bearing cushions and bearings to motor mount |  | 1
 | insert motor/flywheel/shaft assembly into motor mount |  | 1
 | install motor mount in secondary |  | 2
 | attach shaft clamp to primary |  | 1
 | put bolts and nuts on shaft clamp |  | 0.5
 | put shaft spacer on shaft |  | 0.5
 | connect shaft clamp/primary to shaft, press slightly to ensure no axial play |  | 1
 | add shaft clamp to ensure retention. |  | 0.5
 | add electronics board |  | 1
 | wire the connector for the motor-board connection |  | 4
 | test it |  | 5
 | any corrections. Noise must be acceptable. For early units, check stall detection is working |  | 5
 | add the electronics cover |  | 1
 | add motor cover on back |  | 1
 | packaging |  | 10
 | coordination, management, restocking etc. |  | 5
printing
 | all printing |  | 15
 | post processing |  | 10
 | total labor minutes |  | 76.5
 | labor rate cad per hour | 25
 | cost for labor |  | 31.875
 | premises |  | 4
 | electricity, other random stuff |  | 2
 | sum of all labor, parts and costs. cad |  | #NAME?

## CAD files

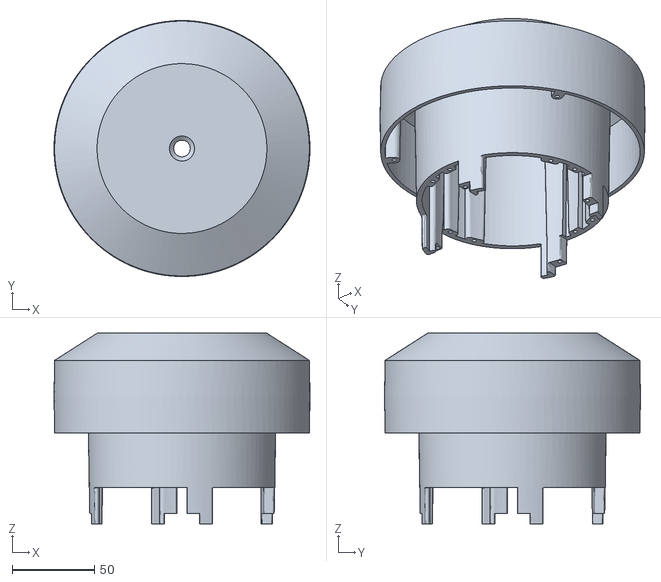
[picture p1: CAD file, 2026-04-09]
dfm v1.0/prototyping stuff/motormountmain10tranglegone.stl
155.3 x 155.3 x 115.7

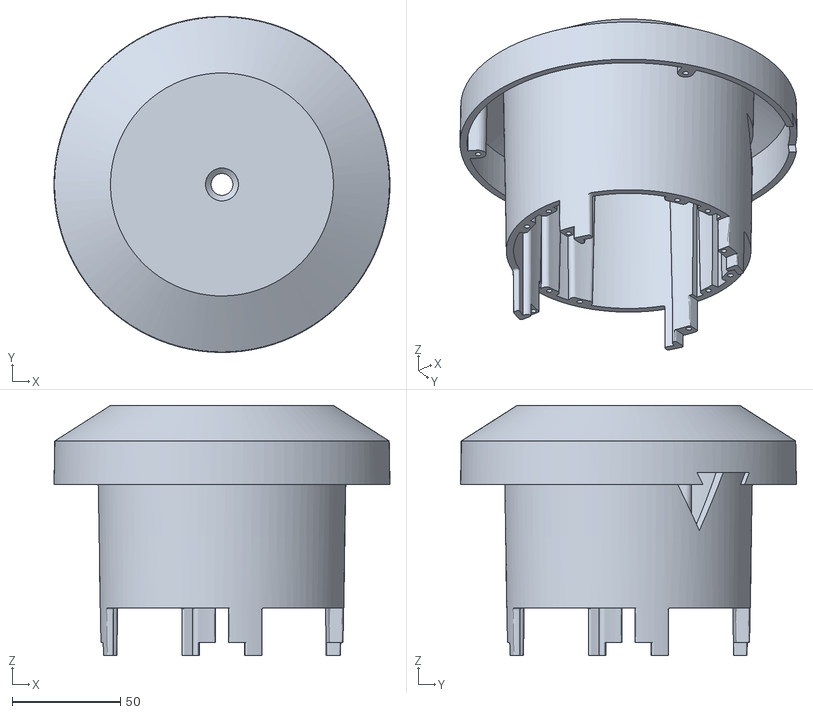
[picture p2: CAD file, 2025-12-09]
dfm v1.0/prototyping stuff/stls/motormountmain modded for prototyping.stl
155.3 x 155.3 x 115.7

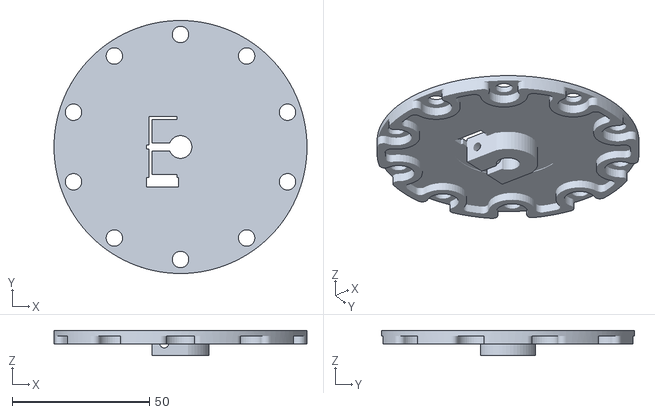
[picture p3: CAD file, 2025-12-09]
dfm v1.0/prototyping stuff/stls/flywheel_fullinfill.stl
92.2 x 92.2 x 9.22

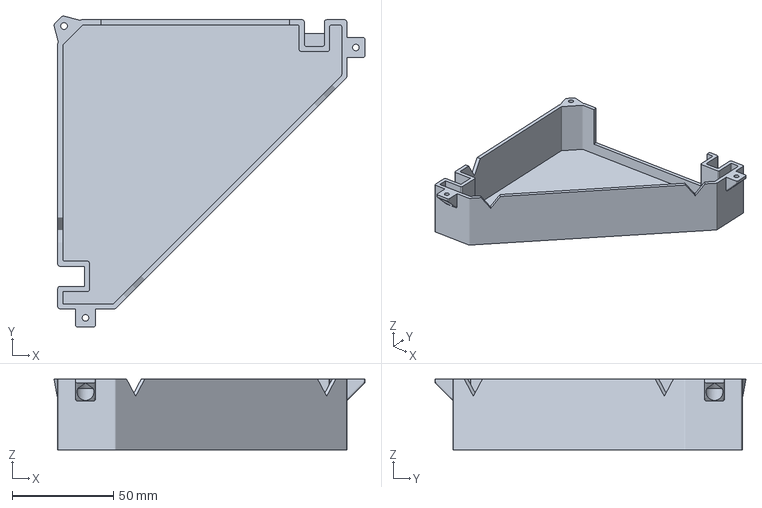
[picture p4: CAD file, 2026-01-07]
dfm v1.0/3mf/electronicscovertaller.3mf
153.9 x 153.9 x 35.0 mm

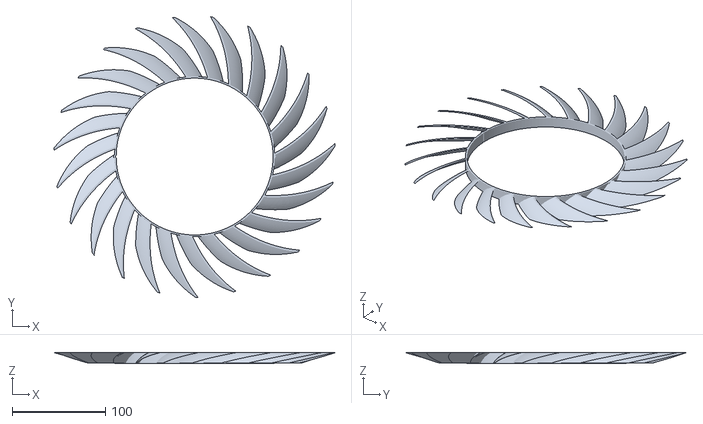
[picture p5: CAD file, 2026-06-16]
dfm v1.0/experimental/middle primary-clearanced6.stl
301.6 x 301.2 x 11.4

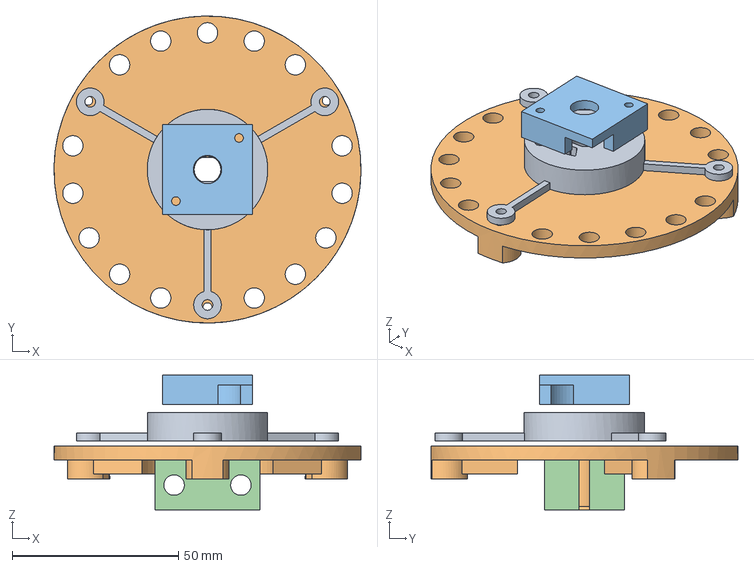
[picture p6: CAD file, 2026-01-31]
dfm v1.0/main design files/jan30shaftcoupler_3arms.step
92.2 x 92.2 x 40.5 mm

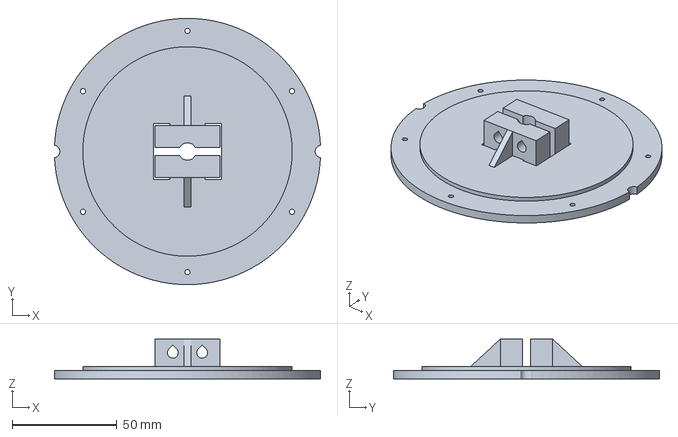
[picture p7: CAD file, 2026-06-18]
dfm v1.0/prototyping stuff/3mf/finished for kits run june 13 onwards/shaft_clamp_infilled_cc3dlakegreenpetgcf_one_0.6_june18_2026.3mf
126.8 x 126.8 x 19.0 mm

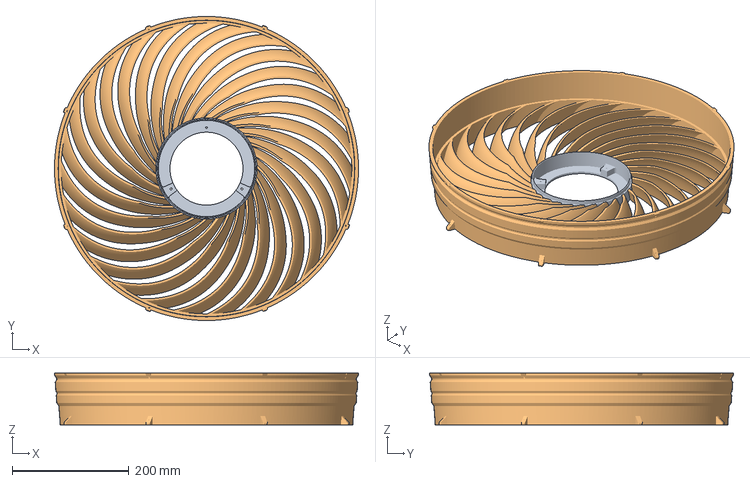
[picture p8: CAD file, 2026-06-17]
dfm v1.0/prototyping stuff/3mf/finished for kits run june 13 onwards/veho-600/secondary moddedforv-series-1mmnozzle-hsjayopetgagain9.3mf
520.9 x 520.9 x 88.8 mm
secondary-framesecondaryprintable_centertry2.stl
secondary-framesecondaryprintable-4.stl

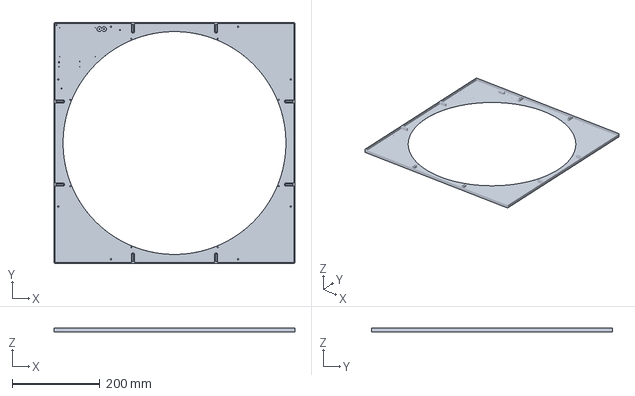
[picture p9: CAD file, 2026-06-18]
dfm v1.0/prototyping stuff/3mf/veho-600/secondary_plate-hsjayopet-1mmnozzle-june18_2026.3mf
550.0 x 550.0 x 10.0 mm

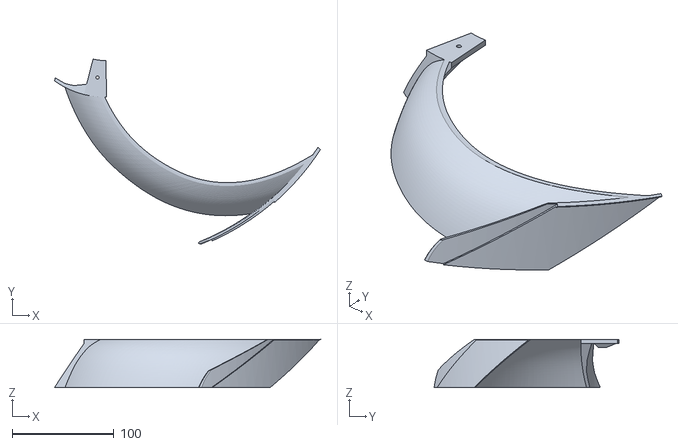
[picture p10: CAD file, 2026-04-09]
dfm v1.0/prototyping stuff/bladetry2.stl
261.5 x 181.6 x 47.4

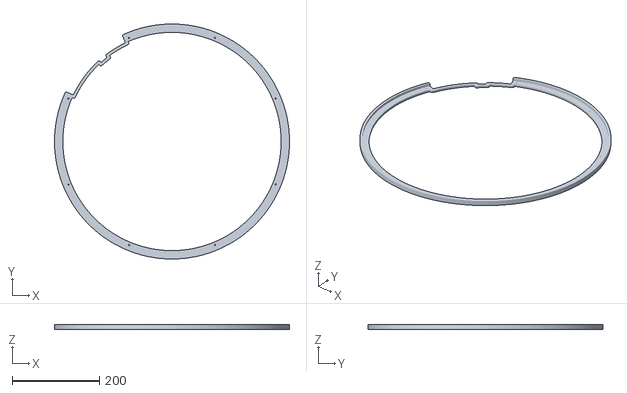
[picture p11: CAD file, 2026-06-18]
dfm v1.0/prototyping stuff/stls/finger_grille_fishnet_ring_partialring.stl
539.9 x 539.9 x 11.0

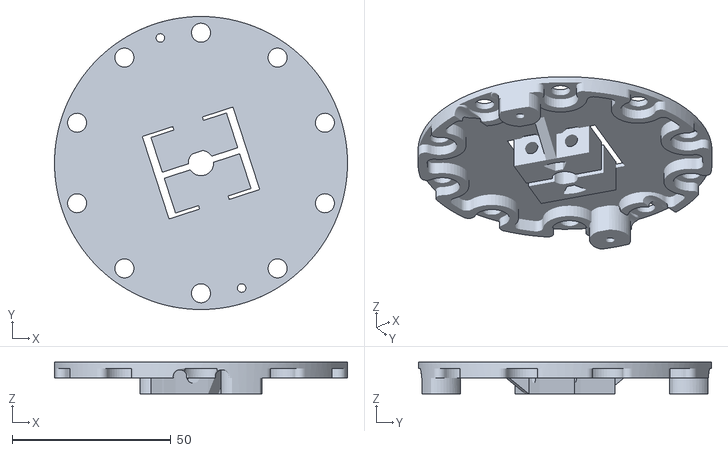
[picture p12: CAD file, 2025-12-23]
dfm v1.0/prototyping stuff/stls/new_coupler3/flywheel6.stl
92.2 x 92.2 x 10.0

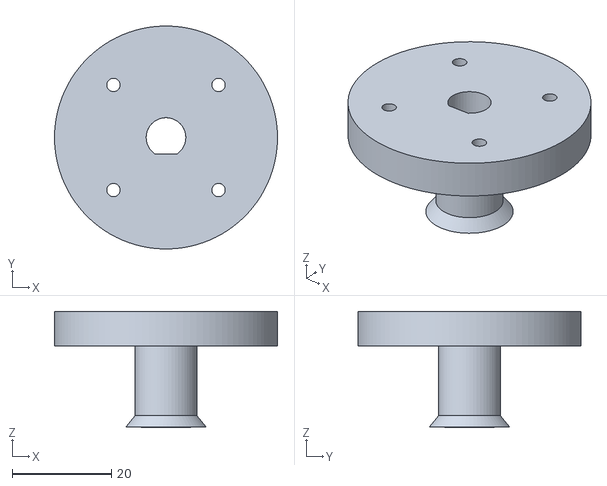
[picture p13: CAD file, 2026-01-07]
dfm v1.0/prototyping stuff/stls/simplificationexperiment/bladeshaftadapter.stl
45.0 x 45.0 x 23.5

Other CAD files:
dfm v1.0/prototyping stuff/motormountmain9nomoretriangle.stl
dfm v1.0/prototyping stuff/stls/motormountmain forprintingroomfororings.stl
dfm v1.0/prototyping stuff/stls/motormountmain_roomfororings.stl
dfm v1.0/prototyping stuff/3mf/shaft_clamp_infilled_petgcf_two_0.6.3mf
dfm v1.0/prototyping stuff/3mf/veho-600/pretty good/secondary moddedforv-series-1mmnozzle-petgsplit7printable.3mf
dfm v1.0/3mf/motor_mount_pla-roomfororings-4.3mf
dfm v1.0/main stuff for use by others/main manufacturing files/cad files/old/march5_BQF_moddingformoldability_primary.step
dfm v1.0/main stuff for use by others/main manufacturing files/old/primary_moldable_try1.step
dfm v1.0/primary_thin_blades_norimstillholes.step
dfm v1.0/prototyping stuff/3mf/bearingcushions 72D.3mf
dfm v1.0/prototyping stuff/3mf/bladeside_coupler.3mf
dfm v1.0/prototyping stuff/3mf/bladesideshaftcollar85A.3mf
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

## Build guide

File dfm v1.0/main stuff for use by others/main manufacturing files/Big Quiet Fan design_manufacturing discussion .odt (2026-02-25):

Online document may be more up to date

https://docs.google.com/document/d/1XwCIWP6nqRXSpk52c2E5IwIIcZ5gb02cDRNazFlFf70/edit?usp=sharing

- Might need more than one shaft spacer between the primary and secondary, on the shaft. Printing makes sense for that part it’s very small and easy, some kind of plastic washers could probably work too, they must not touch the outer race of the bearing though.
- I think we need a wavy/belleville washer on the shaft to keep tension on the bearings, when the TPU or other elastomer creeps, otherwise there is a knocking noise thta intermittently arises.
- The metal spider coupler half in the motor side coupler comes in mirror image versions. Each pair has a mirrored pair. You may wish to mirror the captive thing to make it possible to use the mirror ones too, or maybe source just one type is easier.
- The axial position of the motor is adjustable. A jig should be made which positions the flexure in the right place. It will probably stay by itself due to the interference fit, otherwise, a littl e e6000 might be reasonable. Not too much, we want it to be repairable.
- The holes in the motor flexure do not appear in the cad to align with their counterparts on the motor mount, this is because the whole thing expands some when you put it onthe motor, and the arms also stretch slightly. This keeps things taught.

Sourcing parts/polymer

I sourced a good motor, it required testing various motors.

The sources of the other parts are in the BOM and the source code for the driver board. Sourcing electronic parts is always a bit of a struggle for a board as the pcba guys are always out of stock or can’t get something or other, obviously, so you may need to sub another part in, but there is nothing hard to get.

PCBA notes:

- The large capacitor for the voltage regulator isn’t adequately heat resistant for the usual lowest cost high temperature solder, so you need to use the medium temperature solder. This costs more. I searched and all the capacitors that size are like that. Unless you want to solder the capacitor on by hand looks like we are stuck with that.
- Some of the headers are not inthe bom, this is the way to make them not appear on the board, they are not always needed and there are several different headers/connectors that can be subbed in in those areas. I think they are also soldered by hand which is a drag.

Avoiding various noises

- The motor has to be a good one, some buzz slightly, I do not know why. Some do not. After testing 6, 2 were good ones. One additional one was pretty close.
- The flywheel and it’s damping is not optional. The number of bolts/nuts is hard to reduce, there are a couple more than strictly needed to make it reliable, do not infringe on the safety margin by skimping on the number of bolts. You need at least 8, 10 is not strictly needed. Using another polymer to produce the flywheel may not work, I don’t know.
- Bearing noises can arise if quiet bearings (Z4) are not used, or if the shaft *is* greased where it meets the bearing race or if the fit is a bit tight, increasing vibrational coupling. The shaft may need to be sanded, but try removing the grease first to see if that’s enough. This is generally not noticeable except at lower speeds and in quieter environments. Quality control should have a quiet room or something to detect such issues, I guess.

Motor drive strategy

The motor is driven completely synchronously, with ramping of the RPM speed to avoid excessive loading during speed changes, and ramping of the voltage with RPM in a linear way. This drive strategy has precedence in industry but is not common in smaller motors. It works and is not the same as open loop, the back emf from the motor goes down when the so called torque angle increases, this causes the current to go up, the motor produces more torque to compensate. As long as the RMS/average/peak to peak drive voltage is in the right range, it works great, very efficient, and no sensors or complex current observer systems are needed. I suspect the oscillations the flywheel is dampening are actually partly caused by this feedback process, not merely the accumulation of cogging vibrations.

External board control

The driver board has two interfaces:

- PWM in. You can control fan speed with a 20kHz pwm signal’s duty cycle(which pin on which header) You also need to connect (pin X on header Y numbering starting from A side gpio pin 13 last I checked) to ground to get it to accept PWM commands overriding the potentiometer.
- Serial.
  - You can read RPM, pot position, on/off switch, error status, and current over serial. You cannot recover from stall over serial, that needs user intervention so you need to power cycle the driver. You can change the speed target over serial, in RPM. A micropython script that shows how to do this will be included somewhere, you can see the datagram structure in the arduino code. It’s a command which is a capital letter to set something and a small letter to read something, followed by 7 characters for the the floating point value. It has to be exactly that long. It sends floating point numbers, again the micropython script shows how to parse the reply easily. That’s it.

Warnings re modifications

- Please be sure to retain the space for the wifi board and the anemometer as they are important for long term viablity of the roll out of air purification across institutions, which need to be able to remotely monitor and control their fleet of air purifers for reliablity and labor efficiency. This is an important factor for a school with hundreds of classrooms and failing to retain this could affect roll out at large scales.
- The system as it stands is so quiet it can be used in a bedroom no problem, giving by far the highest card/noise ratio of any air purifier in that context. Please do not cut corners on the degree of quality that allows for this. That’s one of the things that could go seriously wrong, just cutting too many corners and losing the edge that the system has over alternatives due to that. Could we please just actually try making something truly good quality for once ever.

The rim around the blades

I found that the clearance at the edge leads to some leakage, however making the clearances too tight could lead to serious manufacturing issues and interference with the blade and frame when in the horizontal orientation. Therefore I found a solution: make a rim around the edge which seals but can be removed or adjusted in size relatively easily. It could be cut off with a knife, or the mold modified.

Mainly the issue is that the blade sags when mounted horizontally. That’s where most of the clearance goes. But most fans will never encounter that, so adding extra clearance for that doesen’t make that much sense. The rim allows the clearances to be tighter while avoiding serious issues downstream, despite contraction during molding etc.

Warnings of possible pitfalls

- Don’t tweak the blades or the spacing between the primary and secondary, it should be 3-4.5 mm basically, the spacing.
- Not a good idea to skimp on the quality of the polymer used. The higher damping polymer helps considerably.
- You can change the driver board probably without issues much, but watch out for disruption of the stall detection. This also applies to using a different motors, although nema 23 2 Nm motors are mostly the same as each other.
- Obviously the motor wiring has to be correct, and because it’s done by hand that could be an issue. The stall detection will trip if the current is either too high or too low, so wiring errors should be dealth with by that system.
- Make sure you tighten the shaft clamp adequately. Grease could conceivable interfere. Actual nM torque for the fasteners should be figured out and specified.
- The coupler on the motor and the bladeside shaft have to be adequately tight, of course. Actual newton-meter values should be established but I’m sure it won’t be hard to just get good at it and catch any issues by powering the fan to maximal power during quality control. The most critical thing is the actual blade side clamp, as the blade could fall off if it is lose.

Assembly

- It’s important to press the shaft clamp onto the shaft and clamp it such that the bearings are held in position. If they are loose it will rattle. I currently put the whole thing on a piece of foam, this pushes the motor forward which pushes the shaft forward, while the blades/shaft clamp rests on top, giving some force from above. Then tighten the shaft clamp, and that holds pretty well. The shaft spacers are slightly compressible so that helps to provide some springiness, keeping things under moderate tension. Of course these bearings are not good with more than slight axial force so don’t overload it. I think this would be a good assembly method in general during production. It’s reasonably fast and easy and reliable.

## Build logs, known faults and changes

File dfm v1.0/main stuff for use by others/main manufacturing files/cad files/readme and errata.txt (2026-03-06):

There is a flat on the bladeside coupler in the printable version that should be removed. This is corrected in the moldable one.

Some orings are usually used on the three armed coupler between the flywheel and the bladeside piece. These may be optional/useless I don't know yet.

The wavy washer is not shown in the cad file, I just didn't get it in here yet.  There should be a wavy/Belleville washer between the shaft clamp and the spacer that interfaces to the inner race of the bearing.  IT may make sense to have a normal washer on either side of the wavy washer.  Without this, the TPU creeps and a small knocking sound can arise intermittently.

Error: the Belleville washer needed some regular washers too and together they  add about 3.2 mm too much spacing.  the motor mount will have to be moved back to compensate.  Probably move it back ti'' it's 2 mm spacing in he model and you can add extra washers if you need to tothe shaft or washers under themotor mount to move it forward again.  ph and lengthen the shaft a bit in the modle too.

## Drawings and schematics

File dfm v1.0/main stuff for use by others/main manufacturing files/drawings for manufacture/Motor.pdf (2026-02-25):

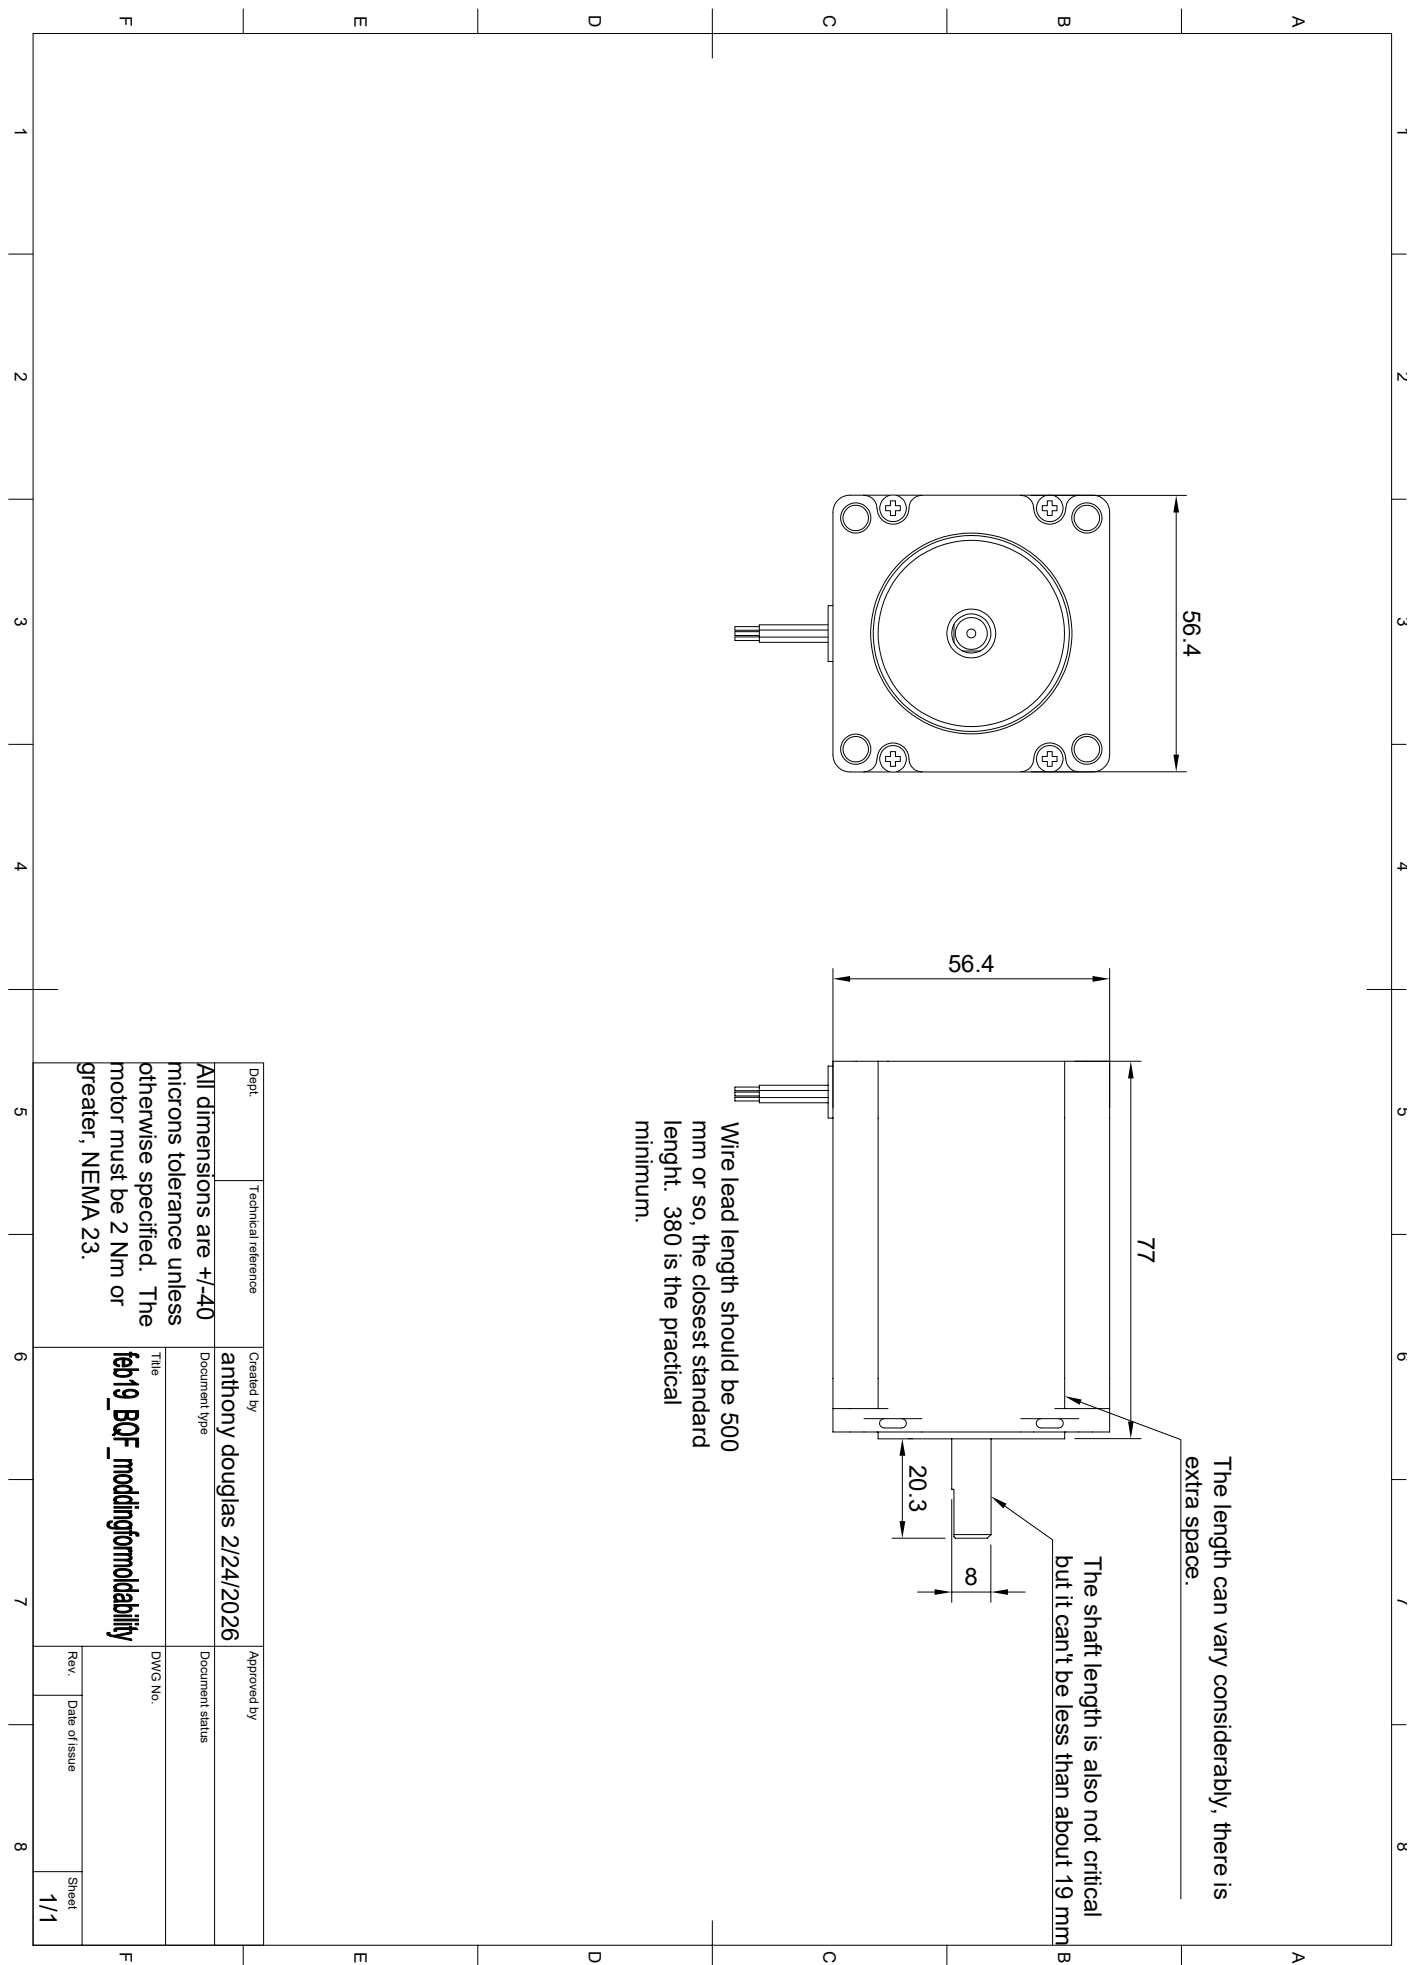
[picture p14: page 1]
extra space. The length can vary considerably, there is greater, NEMA 23. motor must be 2 Nm or otherwise specified. The microns tolerance unless All dimensions are +/-40; but it can't be less than about 19 mm The shaft length is also not critical minimum. lenght. 380 is the practical mm or so, the closest standard Wire lead length should be 500

1 A 2 3 4 5 6 7 8 1 2 3 4 5 6 7 8 FEDCB FEDCBA Dept. Technical reference Created by Approved by Title DWG No. Document type Document status Rev. Date of issue Sheet 2/24/2026 1/1 anthony douglas 8

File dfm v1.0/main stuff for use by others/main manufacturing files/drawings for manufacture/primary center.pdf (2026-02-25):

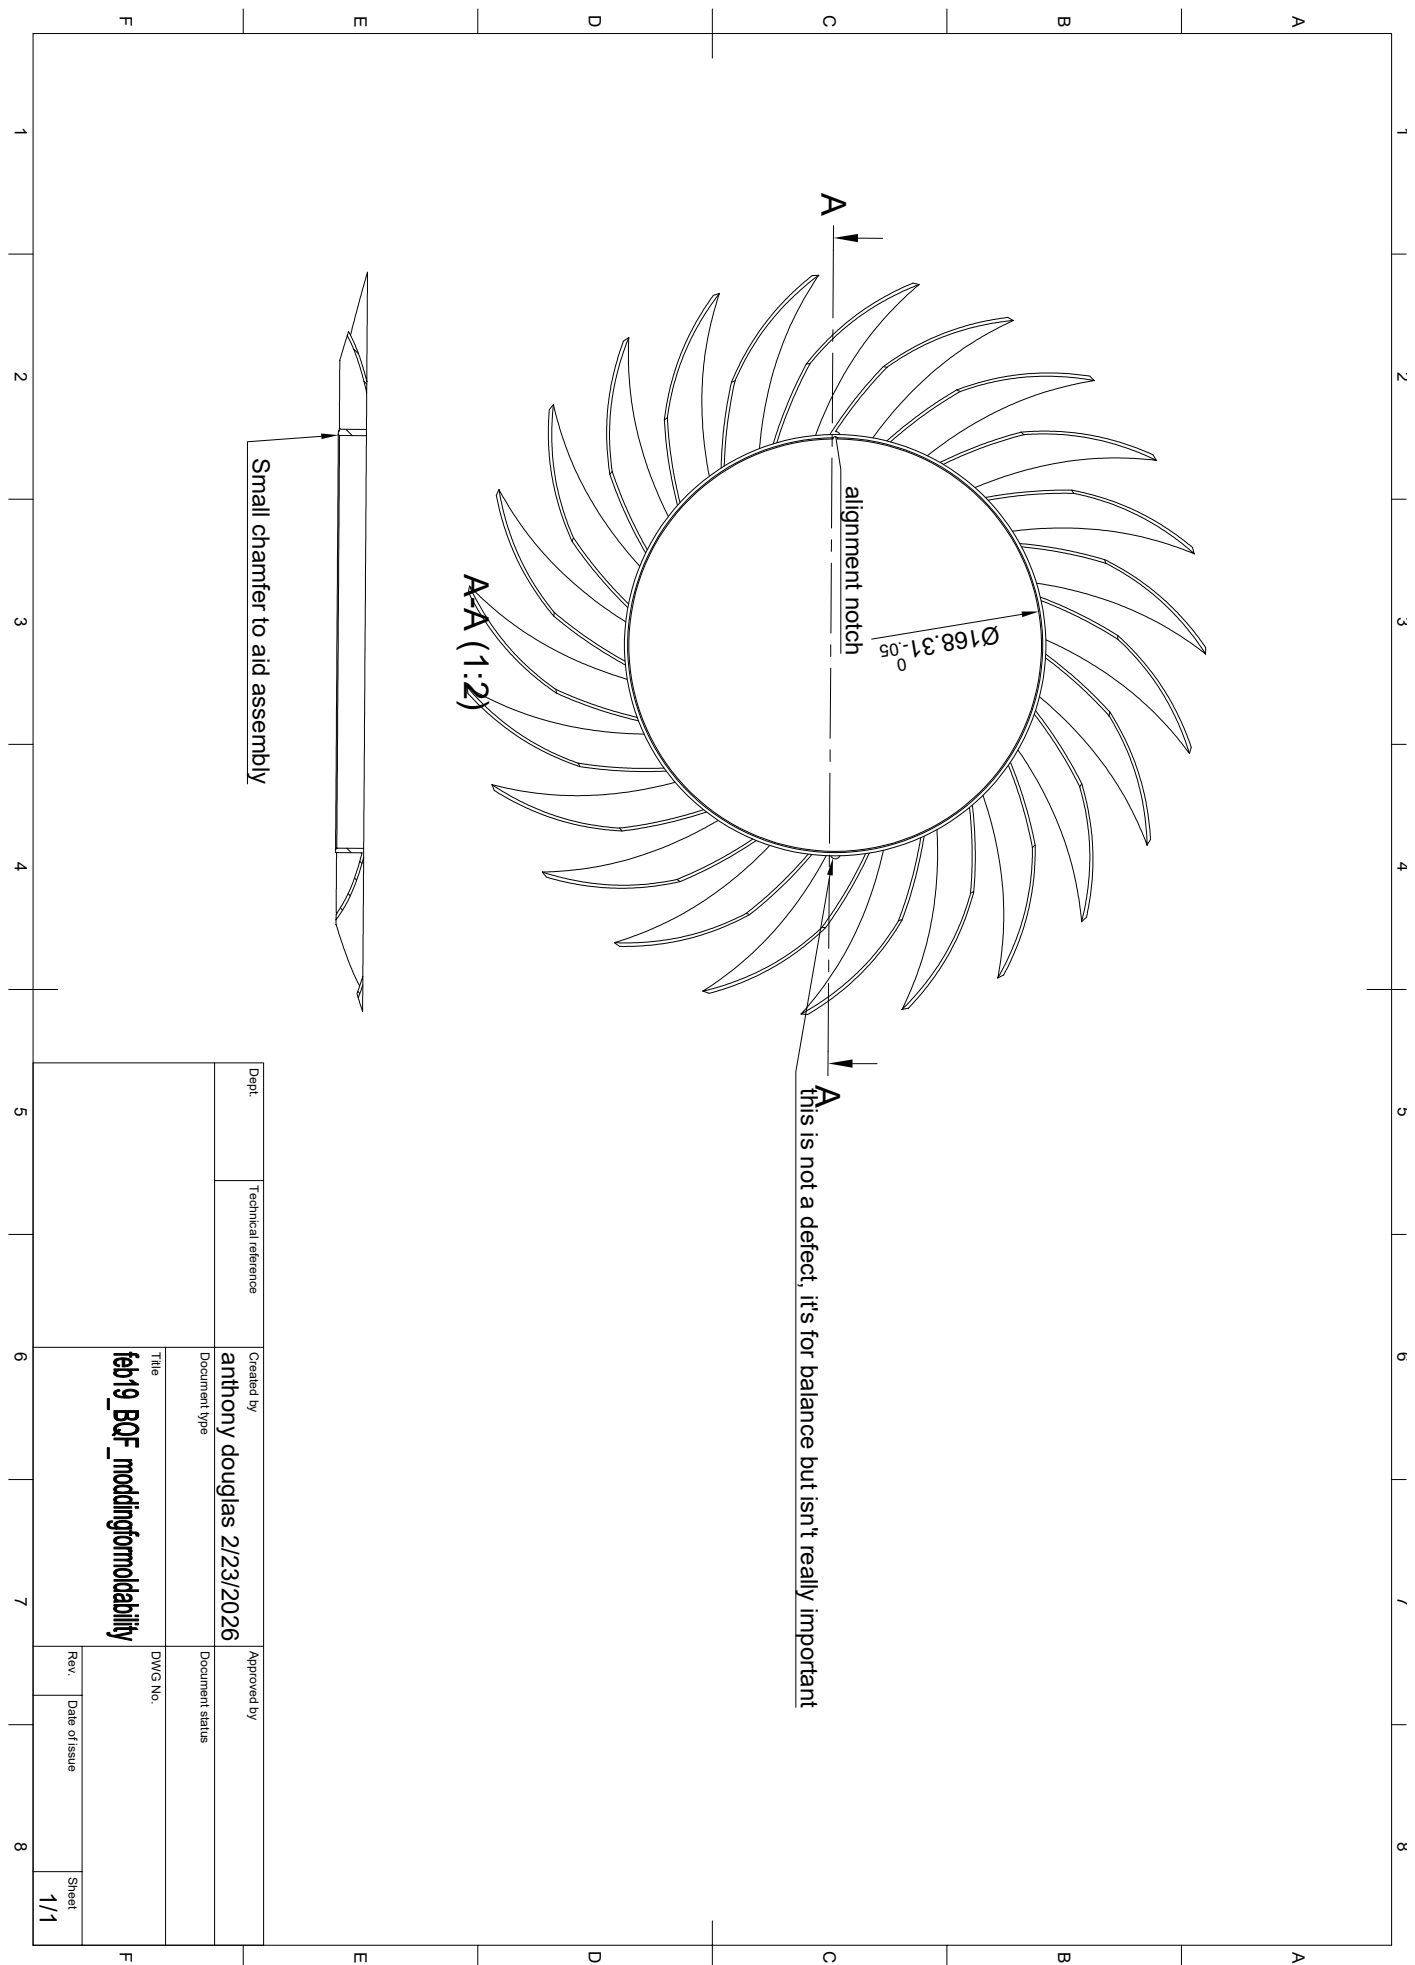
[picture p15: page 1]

1 A 2 3 4 5 6 7 8 1 2 3 4 5 6 7 8 FEDCB FEDCBA Dept. Technical reference Created by Approved by Title DWG No. Document type Document status Rev. Date of issue Sheet 2/23/2026 1/1 anthony douglas this is not a defect, it's for balance but isn't really important alignment notch A A A-A (1:2) Small chamfer to aid assembly Ø168.31 0 50.-

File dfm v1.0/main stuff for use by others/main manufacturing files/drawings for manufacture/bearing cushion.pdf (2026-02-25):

# 3.86 Ø15.1 45° microns default tolerance is +/- 40

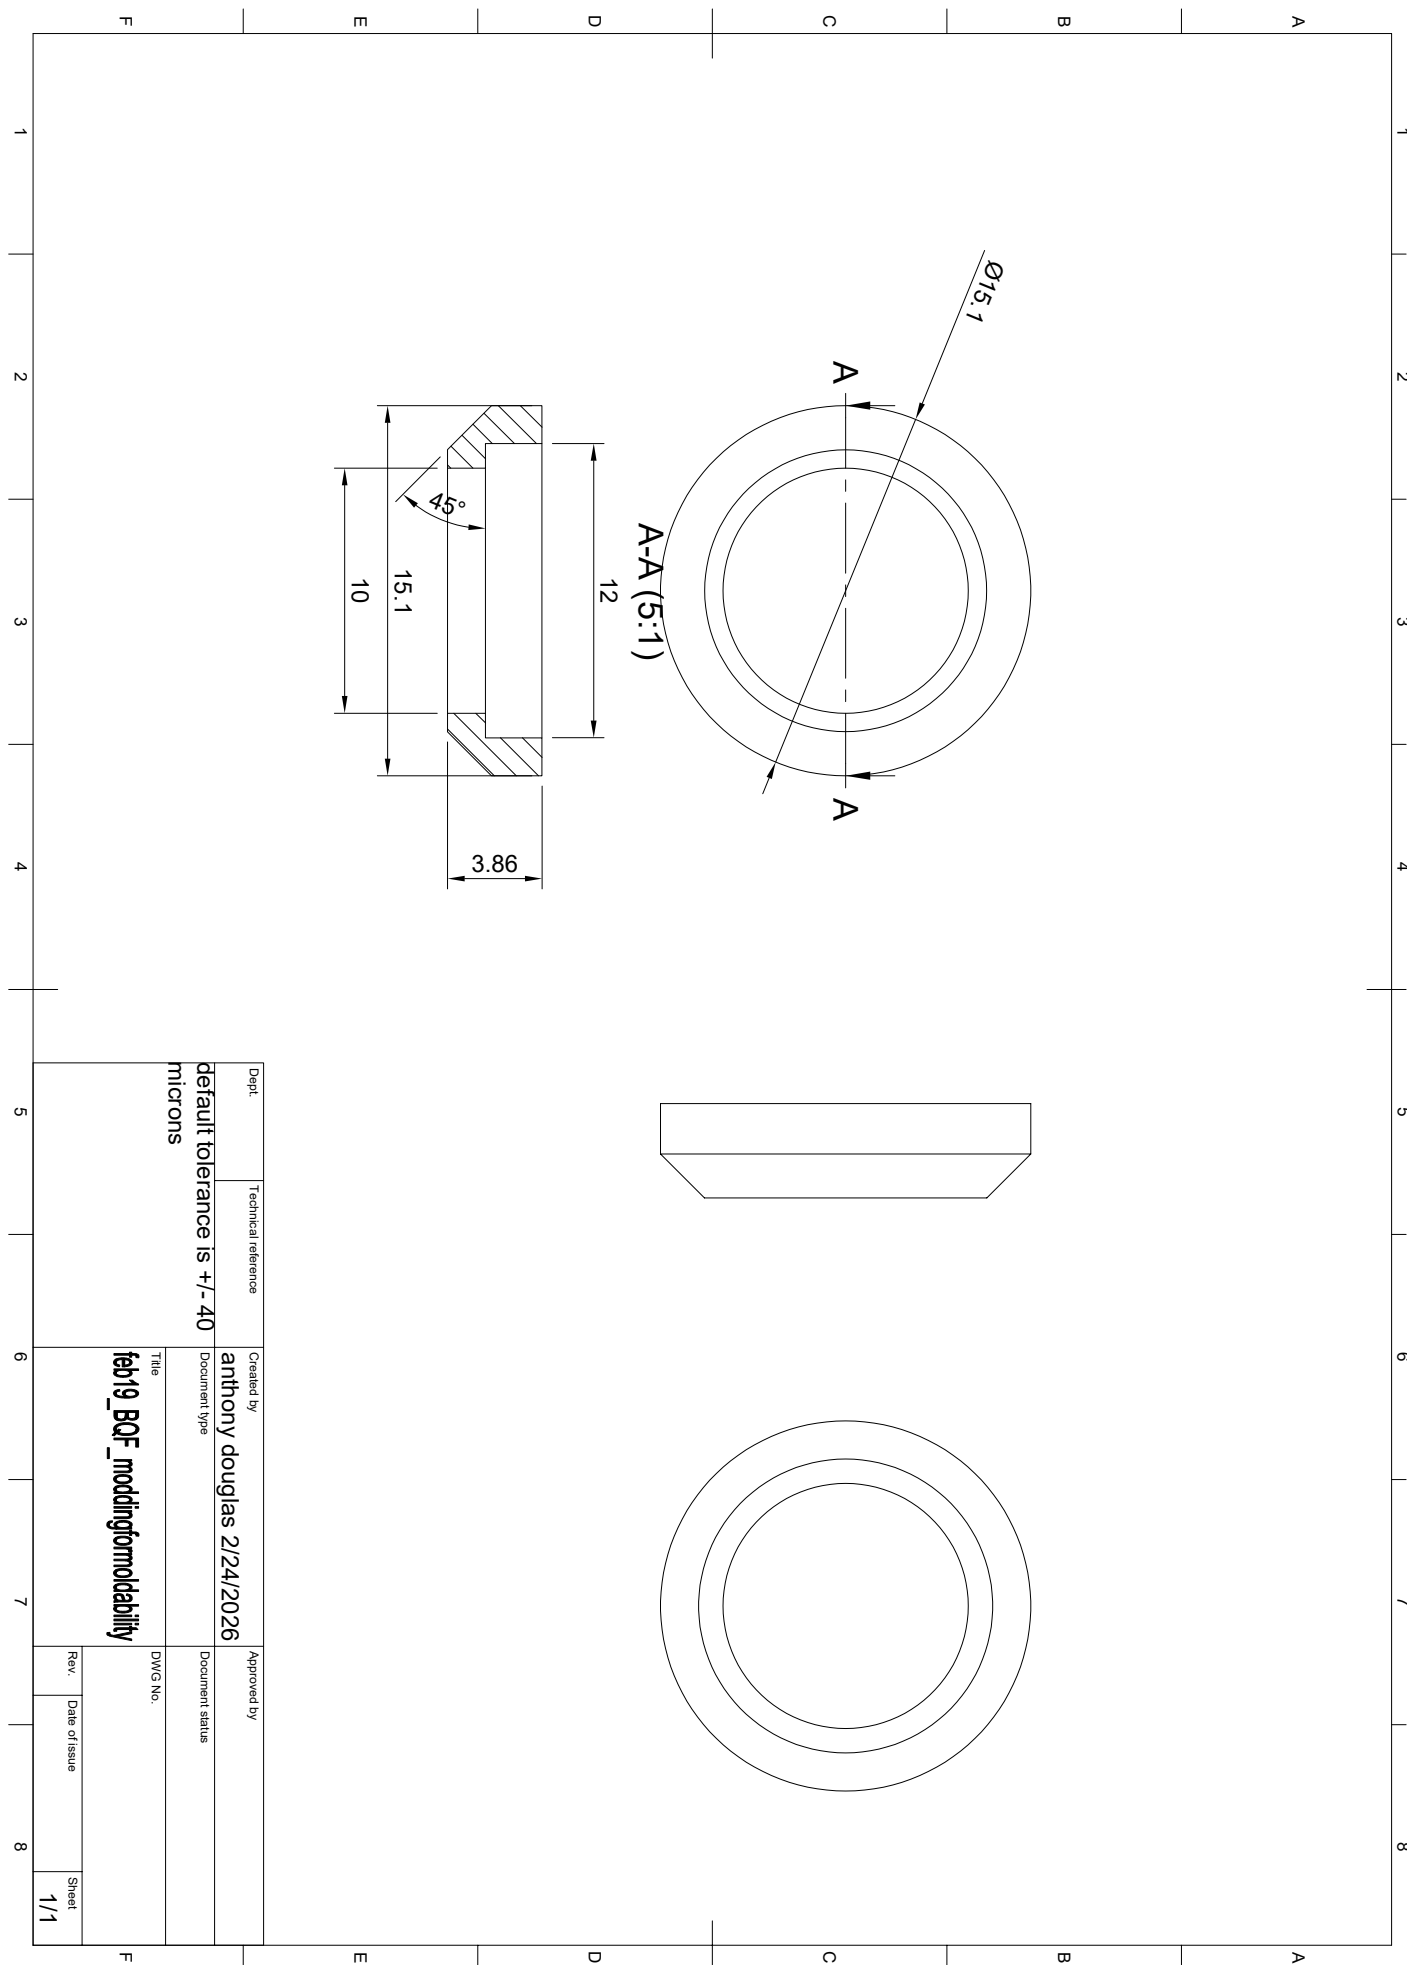
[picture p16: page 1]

1 A 2 3 4 5 6 7 8 1 2 3 4 5 6 7 8 FEDCB FEDCBA Dept. Technical reference Created by Approved by Title DWG No. Document type Document status Rev. Date of issue Sheet 2/24/2026 1/1 anthony douglas A A A-A (5:1) 12 15.1 10

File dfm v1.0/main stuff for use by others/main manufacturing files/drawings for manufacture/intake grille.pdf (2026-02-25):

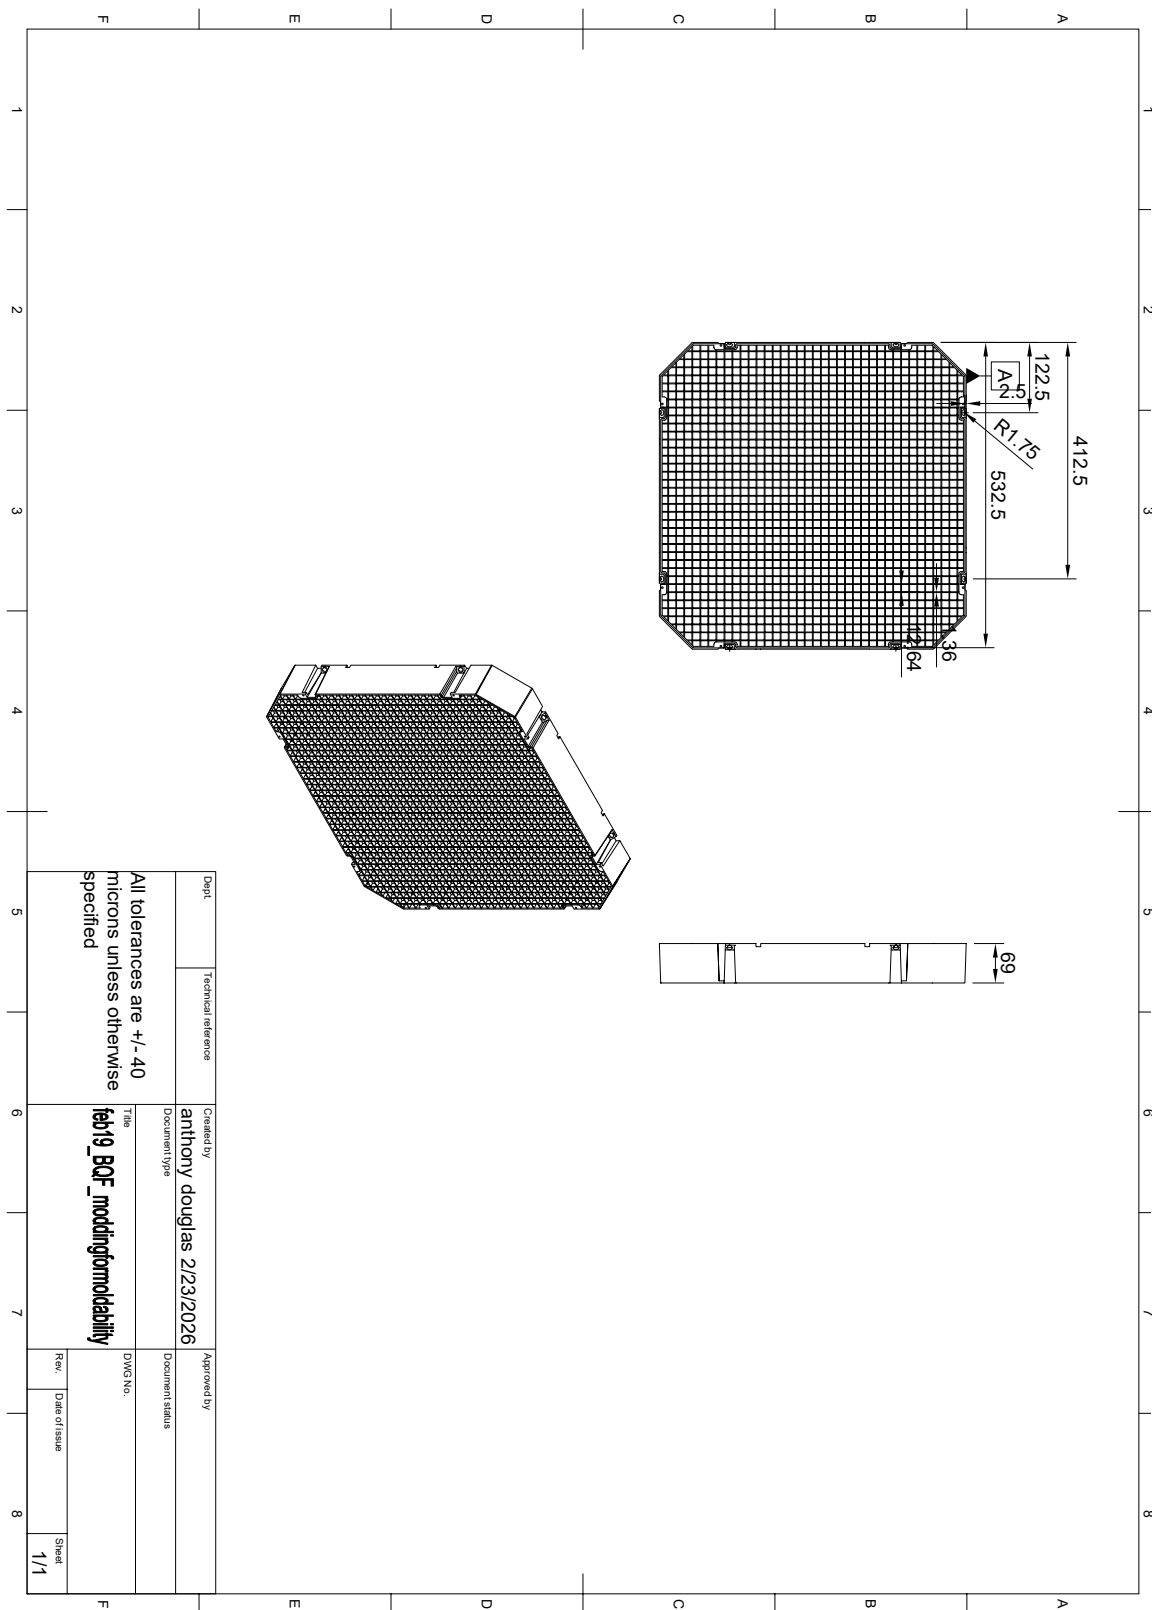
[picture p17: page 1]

1 A 2 3 4 5 6 7 8 1 2 3 4 5 6 7 8 FEDCB FEDCBA Dept. Technical reference Created by Approved by Title DWG No. Document type Document status Rev. Date of issue Sheet 2/23/2026 1/1 anthony douglas A R1.75 122.52.5 412.5532.5 specified microns unless otherwise All tolerances are +/- 40 69 12.64 1.36

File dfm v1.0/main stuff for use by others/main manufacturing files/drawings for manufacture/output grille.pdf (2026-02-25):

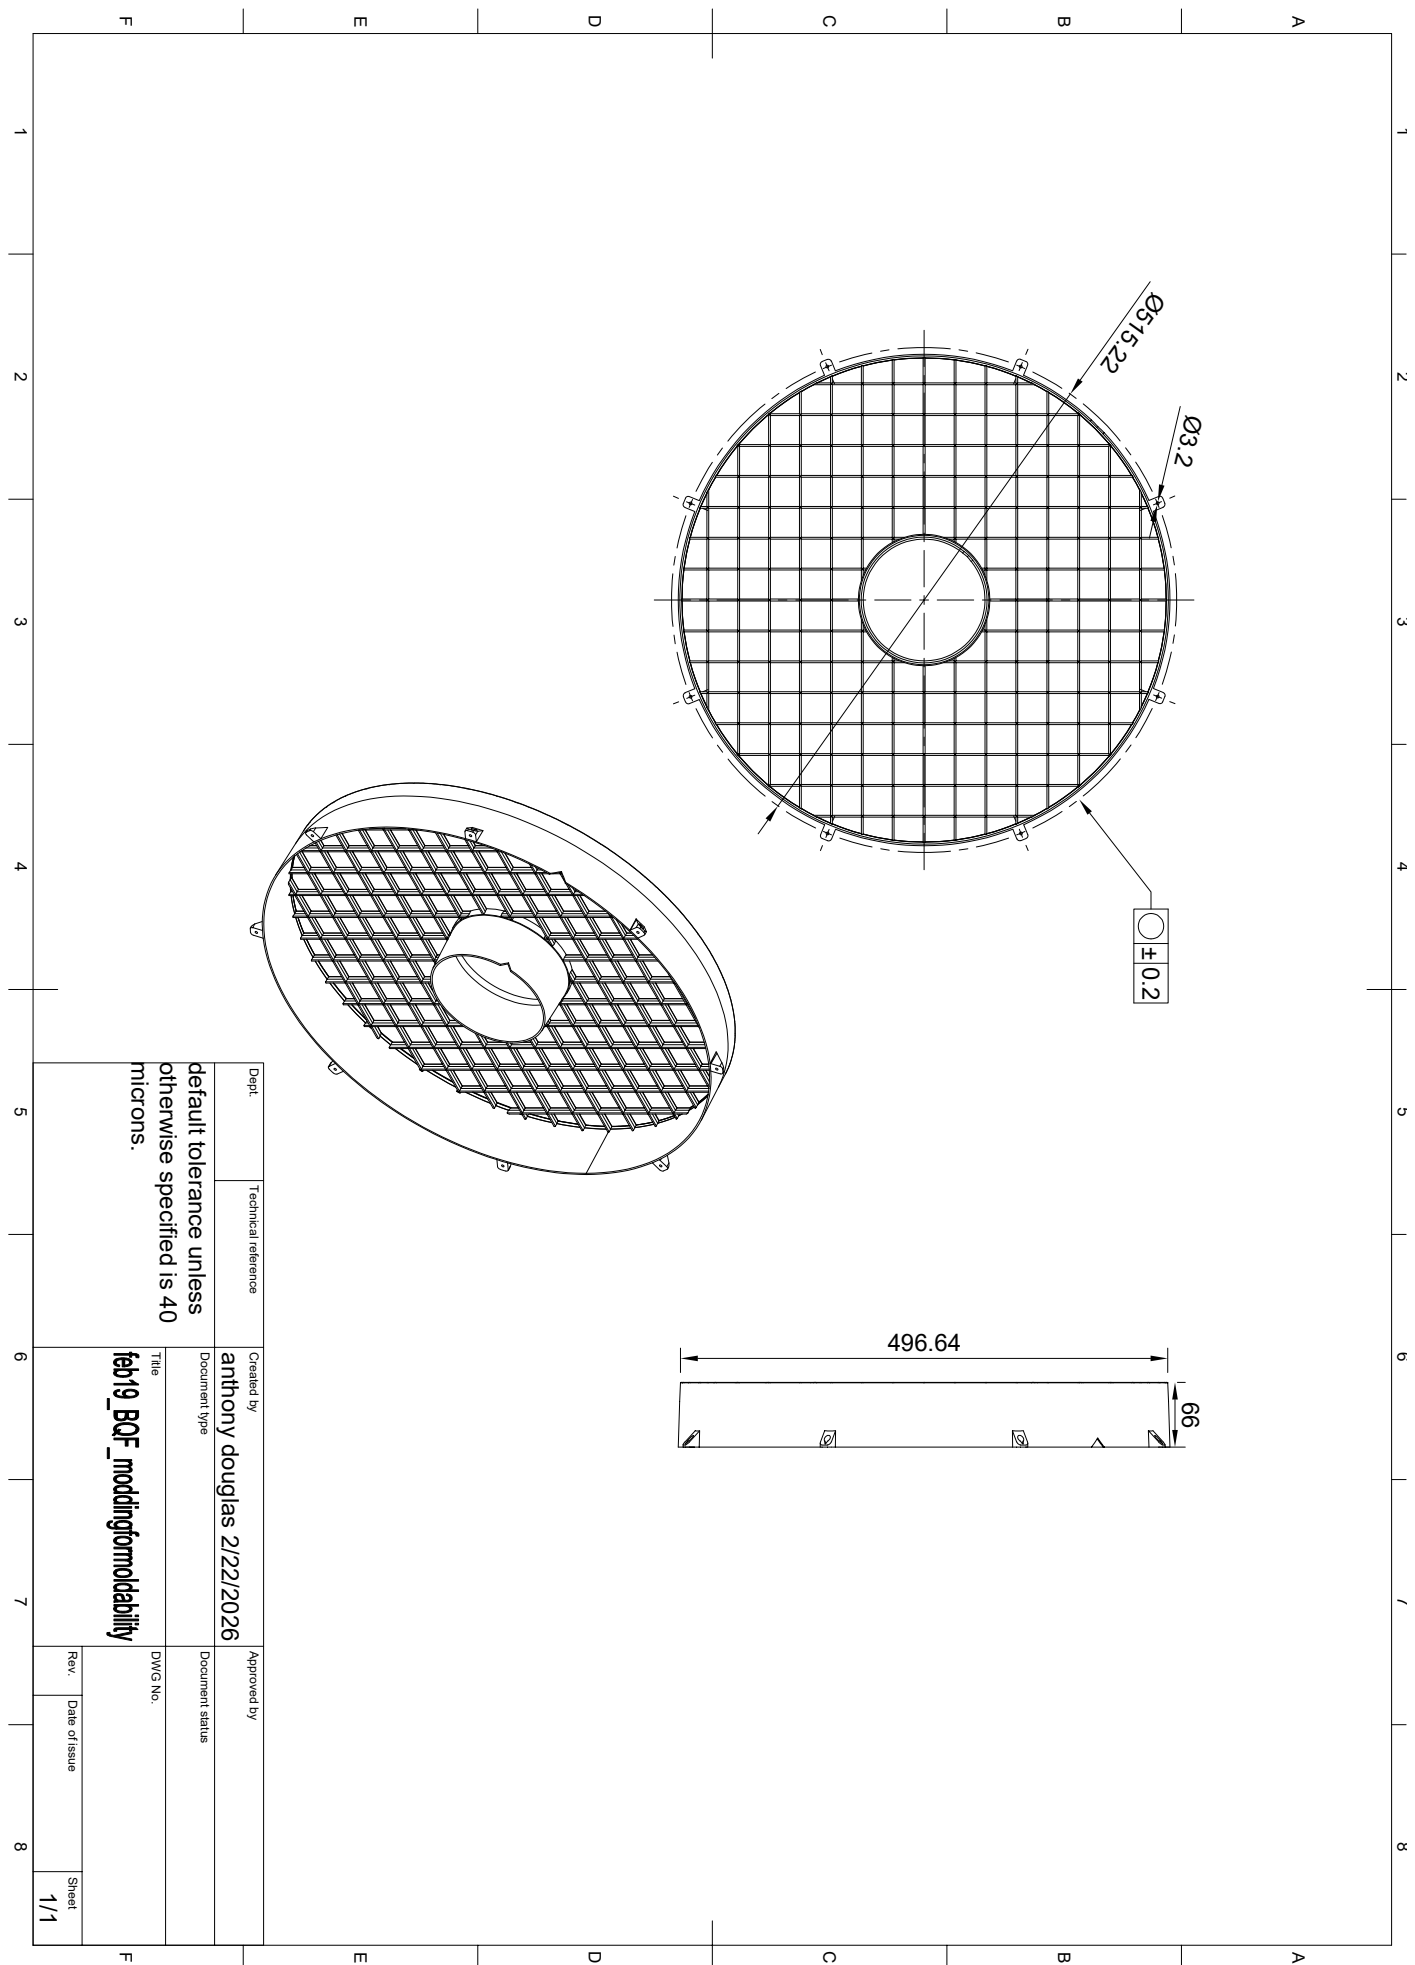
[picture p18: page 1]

1 A 2 3 4 5 6 7 8 1 2 3 4 5 6 7 8 FEDCB FEDCBA Dept. Technical reference Created by Approved by Title DWG No. Document type Document status Rev. Date of issue Sheet 2/22/2026 1/1 anthony douglas Ø515.22Ø3.2 ± 0.2 microns. otherwise specified is 40 default tolerance unless 66

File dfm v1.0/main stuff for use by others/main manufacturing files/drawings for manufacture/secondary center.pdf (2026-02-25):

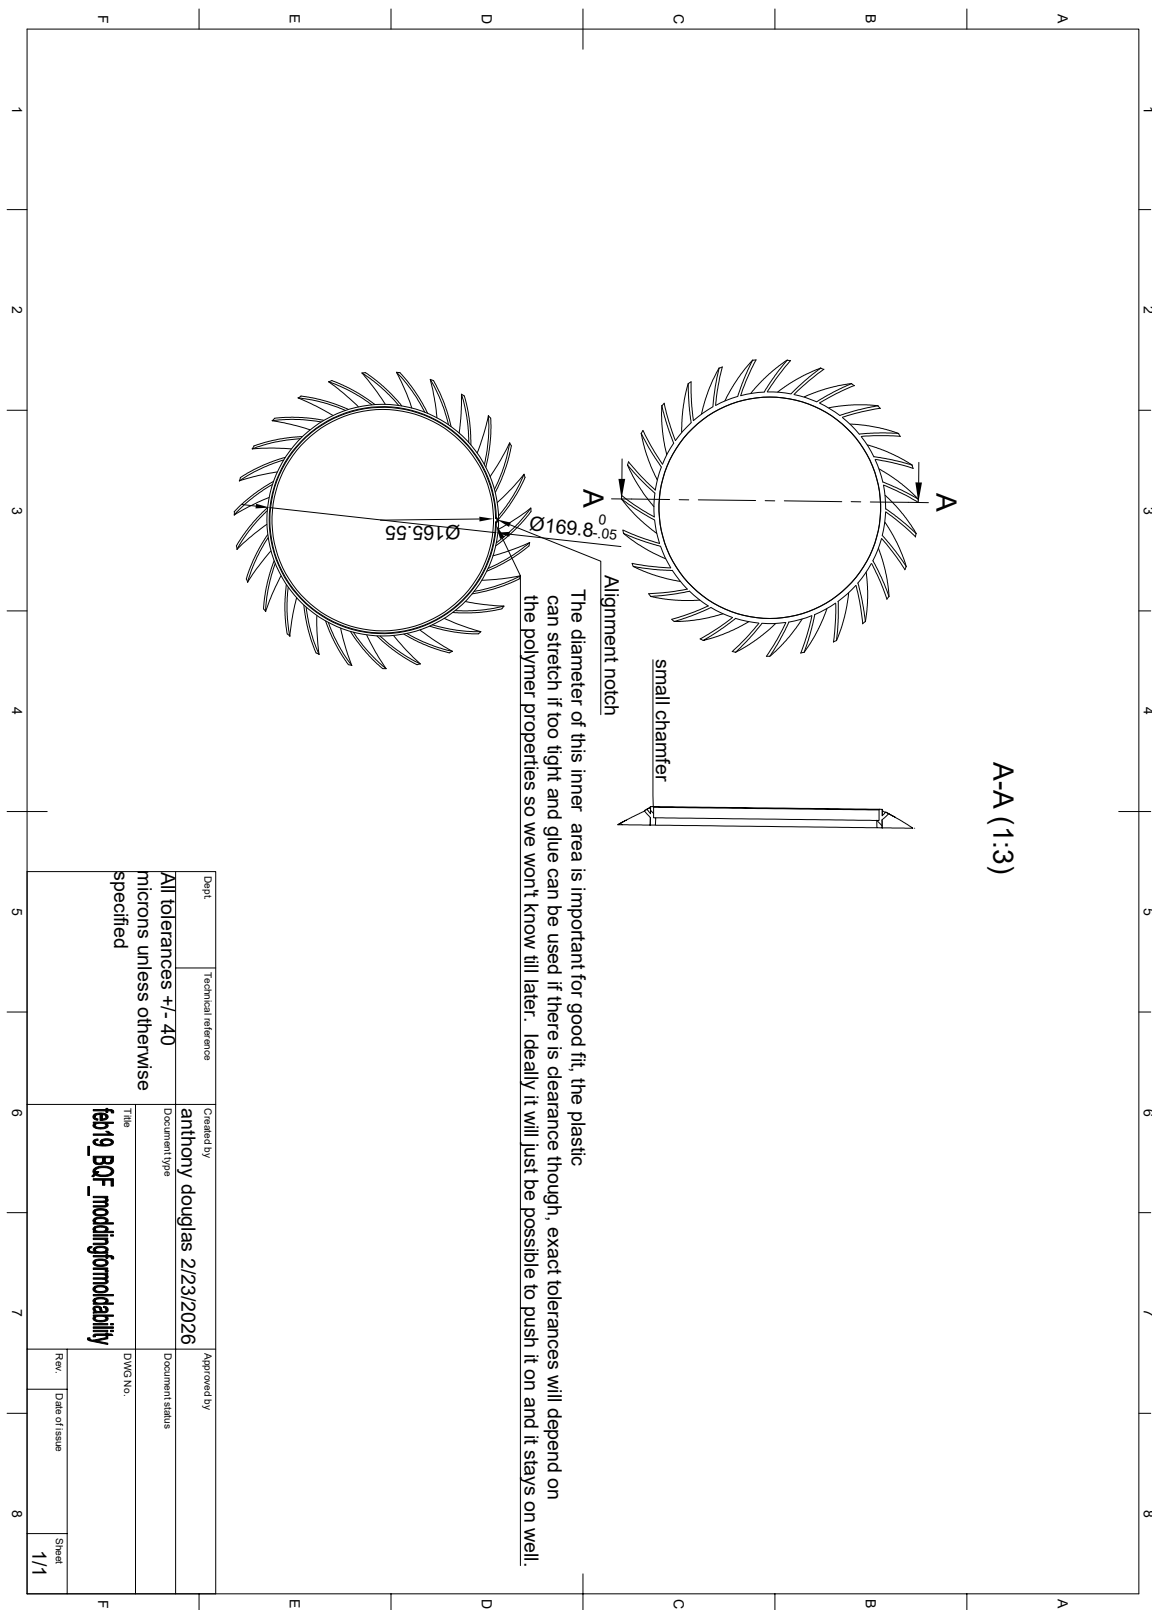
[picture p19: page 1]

1 A 2 3 4 5 6 7 8 1 2 3 4 5 6 7 8 FEDCB FEDCBA Dept. Technical reference Created by Approved by Title DWG No. Document type Document status Rev. Date of issue Sheet 2/23/2026 1/1 anthony douglas AA A-A (1:3) Ø169.8 0-.05 Ø165.55 small chamfer Alignment notch specified microns unless otherwise All tolerances +/- 40 the polymer properties so we won't know till later. Ideally it will just be possible to push it on and it stays on well. can stretch if too tight and glue can be used if there is clearance though, exact tolerances will depend on The diameter of this inner area is important for good fit, the plastic

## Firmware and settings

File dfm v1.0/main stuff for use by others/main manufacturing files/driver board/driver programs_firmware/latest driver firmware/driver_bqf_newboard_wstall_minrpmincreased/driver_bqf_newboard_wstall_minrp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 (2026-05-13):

#include <Arduino.h>
#include <SimpleFOC.h>
#include <math.h>
#include "hardware/pwm.h"
#include "hardware/gpio.h"
#include "hardware/clocks.h"

// ---------- USER PINS (Raspberry Pi Pico 2W) ----------
static const int PIN_PWM_AH = 4;
static const int PIN_PWM_AL = 5;
static const int PIN_PWM_BH = 6;
static const int PIN_PWM_BL = 7;
static const int En_a       = 15;
static const int En_b       = 22;
static const int POT_PIN    = 26;  // ADC0
static const int CURR_PIN   = 28;  // ADC2
static const int use_pwm = 16;
// PWM throttle input (must be PWM B channel, odd GPIO > 12)
static const uint PWM_INPUT_PIN = 13;

// Duty sampler
static const uint32_t SAMPLE_US = 2000;   // 2ms sample window
static const float EMA_ALPHA = 0.15f;

static uint g_slice = 0;
static float g_duty_filt = 0.0f;

// ---------- MOTOR / DRIVER ----------
StepperMotor motor = StepperMotor(50);
StepperDriver4PWM driver = StepperDriver4PWM(PIN_PWM_AH, PIN_PWM_AL, PIN_PWM_BH, PIN_PWM_BL, En_a, En_b);

float duty = 0.0f;
float voltage_override = 1.0f;
float expected_current2 = 0.0f;
float target = 0.0f;
 float norm = 0.0f;
// ---------- SPEED ----------
volatile float RPS       = 0.0f;
volatile float RPS_accel = 0.3f;    // rps^2
volatile float rps_max   = 6.95f;
volatile float rps_min   = 3.6f;
const float    HYST_RPS  = 0.1f;
unsigned long  lastMicros = 0;
float cmd_rad_per_sec = 0.0f;
float curr = 0.0f;

// ---------- PWM INPUT INIT ----------
void pwm_duty_input_init(uint gpio) {
  if (pwm_gpio_to_channel(gpio) != PWM_CHAN_B) {
    while (true) {
      Serial.println("ERROR: PWM_INPUT_PIN must be a PWM B-channel GPIO (odd-numbered).");
      delay(1000);
    }
  }

  gpio_set_function(gpio, GPIO_FUNC_PWM);
  g_slice = pwm_gpio_to_slice_num(gpio);

  pwm_config cfg = pwm_get_default_config();
  pwm_config_set_clkdiv_mode(&cfg, PWM_DIV_B_HIGH);

  // Must match the read function
  const float clkdiv = 256.0f;
  pwm_config_set_clkdiv(&cfg, clkdiv);

  pwm_init(g_slice, &cfg, true);
  pwm_set_counter(g_slice, 0);
}

// ---------- PWM DUTY READ (NONBLOCKING + OVERFLOW SAFE) ----------
float pwm_duty_read_nonblocking() {
  static uint32_t last_sample_us = 0;
  static bool started = false;

  uint32_t now = micros();

  // On first call, just arm the timing and clear counter
  if (!started) {
    started = true;
    last_sample_us = now;
    pwm_set_counter(g_slice, 0);
    return g_duty_filt;
  }

  uint32_t dt_us = now - last_sample_us;
  if (dt_us < SAMPLE_US) {
    return g_duty_filt;
  }

  uint16_t high_counts = pwm_get_counter(g_slice);

  // Reset for next window
  pwm_set_counter(g_slice, 0);
  last_sample_us = now;

  // Convert counts -> duty
  const float f_sys = (float)clock_get_hz(clk_sys);
  const float clkdiv = 256.0f;  // must match init()
  const float count_rate = f_sys / clkdiv; // counts/sec when HIGH
  const float window_s = (float)dt_us * 1e-6f;

  const float max_counts = count_rate * window_s;
  float d = (max_counts > 0.0f) ? ((float)high_counts / max_counts) : 0.0f;

  if (d < 0.0f) d = 0.0f;
  if (d > 1.0f) d = 1.0f;

  // Optional smoothing (does NOT fix overflow; overflow is already prevented by frequent sampling)
  g_duty_filt += EMA_ALPHA * (d - g_duty_filt);
  return g_duty_filt;
}

// ---------- CURRENT READ ----------
float read_current_units() {
  int raw = analogRead(CURR_PIN);
  return 3.3f * (float)raw / 4095.0f;
}

bool stall_detect(float x, float current) {
  const float TAU_S = 0.16f;
  static float current_filt = 0.0f;
  static bool initialized = false;
  static unsigned long last_us = 0;

  unsigned long now_us = micros();
  float dt = 0.0f;

  if (last_us != 0) {
    dt = (now_us - last_us) * 1e-6f;
    if (dt < 0.0f) dt = 0.0f;
    if (dt > 0.25f) dt = 0.25f;
  }
  last_us = now_us;

  if (!initialized) {
    current_filt = current;
    initialized = true;
  } else {
    float alpha = dt / (TAU_S + dt);
    current_filt = current_filt + alpha * (current - current_filt);
  }

  float expected_current =
      0.001f * powf(x, 4) -
      0.0141f * powf(x, 3) +
      0.1142f * powf(x, 2) -
      0.3059f * x +
      0.4257f;

  expected_current2 = expected_current;
  curr = current_filt;

  if ((expected_current * 0.6f < current_filt) &&
      (current_filt < expected_current * 1.2f + 0.15f)) {
    return false;
  } else {
    return true;
  }
}

// ---------- SETUP ----------
void setup() {
  Serial.begin(1000000);
  Serial.setTimeout(1);

  pinMode(PIN_PWM_AH, OUTPUT_12MA);
  pinMode(PIN_PWM_AL, OUTPUT_12MA);
  pinMode(PIN_PWM_BH, OUTPUT_12MA);
  pinMode(PIN_PWM_BL, OUTPUT_12MA);
  pinMode(LED_BUILTIN, OUTPUT);
pinMode(use_pwm, INPUT_PULLUP);
  pwm_duty_input_init(PWM_INPUT_PIN);

  analogReadResolution(12);

  driver.voltage_power_supply = 24.0f;
  driver.voltage_limit        = 24.0f;
  driver.pwm_frequency        = 30000;
  if (!driver.init()) {
    Serial.println("Driver init failed!");
    while (1) { delay(1000); }
  }
  driver.enable();

  motor.linkDriver(&driver);
  motor.controller           = MotionControlType::velocity_openloop;
  motor.velocity_limit       = 60.0f;
  motor.foc_modulation       = FOCModulationType::SinePWM;
  motor.modulation_centered  = false;
  motor.init();

  lastMicros = micros();
}

// ---------- LOOP ----------
bool started = false;
void loop() {
  static unsigned long lastPrintMs = 0;
  static const unsigned long printIntervalMs = 500;
  unsigned long nowMs = millis();
  float Iraw = read_current_units();
  if (nowMs - lastPrintMs >= printIntervalMs) {
    lastPrintMs = nowMs;
   Serial.print("voltage: "); Serial.println(motor.voltage_limit); 
   Serial.print("voltage override: "); Serial.println(voltage_override);
   Serial.print("current: "); Serial.println(Iraw);
   Serial.print("expected_current2: "); Serial.println(expected_current2);
  if (digitalRead(use_pwm) == 0){
    Serial.print("status: "); Serial.println("using pwm as throttle input");
  }
    else {
  Serial.print("status: "); Serial.println("using potentiometer as throttle input");
  }
  }
  
  if (digitalRead(use_pwm) == 0){
    duty = pwm_duty_read_nonblocking();
    norm = duty;
  }
  else {
  int raw = analogRead(POT_PIN);
  norm   = (float)raw / 4095.0f;      // 0..1
  }
 
  target = norm * rps_max;
  //logic to get it to turn off fully at lower power command levels, remember there is no stall detect below a certain rps so it's important not to allow operation in that region for long
  if (target < rps_min){
    target = 0;
  } 
   if (RPS<(HYST_RPS+0.10)){  
    voltage_override = 0.0f;
    started = false;
  }
else{
  if (started == false){
voltage_override = 1.0f;
started = true;
  }
  
}

  unsigned long now = micros();
  float dt = (now - lastMicros) * 1e-6f;
  lastMicros = now;

  // RPS ramp
  float err = target - RPS;
  if (fabsf(err) > HYST_RPS) {
    float maxStep = RPS_accel * dt;
    if (err > 0.0f) RPS += min(err,  maxStep);
    else            RPS += max(err, -maxStep);
  }
  RPS = constrain(RPS, 0.0f, rps_max);

  float Vbase = (22.0f * (RPS / rps_max)) + 2.5f;
  Vbase = constrain(Vbase, 2.5f, 24.0f);

  cmd_rad_per_sec = RPS * 2.0f * PI;

  motor.voltage_limit = (Vbase * voltage_override);

  if (RPS > 2.8f) {
    if (stall_detect(RPS, Iraw)) {
      voltage_override = 0.0f;
    }
  }

  // Keep motor running
  motor.move(cmd_rad_per_sec);
}

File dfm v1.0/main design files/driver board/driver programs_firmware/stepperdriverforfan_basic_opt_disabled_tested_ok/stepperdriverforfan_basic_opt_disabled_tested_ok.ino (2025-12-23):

#include <Arduino.h>
#include <SimpleFOC.h>
#include <math.h>

// ---------- USER PINS (Raspberry Pi Pico 2W) ----------
static const int PIN_PWM_AH = 4;
static const int PIN_PWM_AL = 5;
static const int PIN_PWM_BH = 6;
static const int PIN_PWM_BL = 7;
static const int En_a       = 8;
static const int En_b       = 9;
static const int POT_PIN    = 26;  // ADC0
static const int CURR_PIN   = 28;  // ADC2

// ---------- MOTOR / DRIVER ----------
StepperMotor motor = StepperMotor(50);
StepperDriver4PWM driver = StepperDriver4PWM(PIN_PWM_AH, PIN_PWM_AL, PIN_PWM_BH, PIN_PWM_BL, En_a, En_b);

float anticog_multiplier = 25.0f;//this should be the number of pole pairs but a float
float voltage_override = 1.0f;

float maybe_o = 0.0f;
const int lut_size = 200; // Adjust size as needed
float lut[lut_size]; // Lookup table
int indexa = 0;
// ---------- SPEED / POT ----------
volatile float RPS       = 0.0f;
volatile float RPS_accel = 0.3f;    // rps^2 
volatile float rps_max   = 7.2f;
const float    HYST_RPS  = 0.1f;    // rps hysteresis band
unsigned long  lastMicros = 0;
float v_drive_befoverlay = 3.0f;
float cmd_rad_per_sec = 0.0f;
// ---------- CURRENT READ ----------
float read_current_units() {
  // raw ADC voltage (0..3.3 V) proportional to current; absolute amps not required for minimization
  int raw = analogRead(CURR_PIN);
  return 3.3f * (float)raw / 4095.0f;
}
void stall_detect(){
 if (read_current_units() > 1.4){
   voltage_override = 0.0f;
 }

}
void receiveLUT() {
    int index2 = 0;
    int counter = 0;
    Serial.println("ready for lut");

    while (index2 < lut_size) {
        if (Serial.available() >= 5) { // 4 bytes float + 1 bytes checksum +1 end byte
            byte buffer[4];
            for (int i = 0; i < 4; i++) {
                buffer[i] = Serial.read();
            }

            byte received_checksum = Serial.read(); 

            // Calculate checksum
            byte calculated_checksum = 0;
            for (int i = 0; i < 4; i++) {
                calculated_checksum ^= buffer[i];
            }

            if (calculated_checksum == received_checksum) {
                // Convert bytes to float
                float received_value;
                unsigned char *valueBytes = (unsigned char*)&received_value;
                for (int i = 0; i < 4; i++) {
                    valueBytes[i] = buffer[i];
                }

                lut[index2] = received_value;

                // Send acknowledgment
                Serial.println("A");


                index2++;
            } else {
                Serial.println("N");
            }
        }
motor.move(cmd_rad_per_sec); //gotta keep motor moving
    
    }

    //Serial.println("LUT Received");
}
void initialize_lut() {
    for (int i = 0; i < lut_size; i++) {
        lut[i] = 0.0f;
    }
}

void SerialComm() {
    if (Serial.available() > 0) {
        switch (Serial.peek()) {
            case 's': Serial.read(); Serial.print("s"); Serial.println(motor.shaftVelocity()); break;
            case 'b': Serial.read(); Serial.print("b"); Serial.println(anticog_multiplier); break;
            case 'U': Serial.read(); anticog_multiplier = Serial.parseFloat(); break;
            case 'L': Serial.read();  receiveLUT(); break;
            case 'O':
                Serial.read();
                maybe_o = Serial.parseFloat();
                voltage_override = (maybe_o >= 0.999) ? 1.0f : 0.0f;
                break;
            default: Serial.read(); break;
        }
    }
}

float anti_cog_voltage() {
    float anticog_angle = fmod(motor.shaft_angle * motor.pole_pairs, 2.0f * PI);
    indexa = int(((anticog_angle / (2.0f * PI)) * float(lut_size-1)));  
    return lut[indexa];
}
// ---------- OPTIMIZER (ΔV trim around base voltage) ----------
struct MinCurrentTrimOpt {
  // Voltage bounds (motor command)
  float Vmin = 3.0f;
  float Vmax = 24.0f;

  // Trim state (what we adjust): Vcmd = clamp(Vbase + trim)
  float trim = 0.0f;

  // Step logic
  float step     = 0.10f;   // initial trim step (V)
  float step_max = 0.30f;
  float step_min = 0.02f;
  int   dir      = +1;      // +1 / -1

  // Filtering & decision
  float Ibar   = 0.0f;      // EMA of current
  float alpha  = 0.15f;     // EMA coeff (0..1)
  float Iref   = INFINITY;  // drifting reference (best so far with drift)
  float eps    = 0.02f;     // significant improvement threshold 
  float drift  = 0.003f;    // upward drift rate for Iref (keeps optimizer adaptive)

  // Timing
  uint32_t lastTickUs = 0;
  uint32_t periodUs   = 10000;  // 10 ms tick
  int      settleTicks = 8;     // ~80 ms settle after each voltage change
  int      settleLeft  = 0;

  // simple rate-limited debugging
  uint16_t printEvery = 25;
  uint16_t printCnt   = 0;

  // helpers
  inline float clampV(float v) const { return constrain(v, Vmin, Vmax); }

  static inline float ema(float prev, float sample, float a) {
    return prev + a * (sample - prev);
  }

  void init() {
    trim = 0.0f;
    step = 0.10f;
    dir  = +1;
    Ibar = 0.0f;
    Iref = INFINITY;
    settleLeft  = settleTicks;
    lastTickUs  = micros();
    printCnt    = 0;
  }

  void applyCommand(float Vbase) {
    float Vcmd = clampV(Vbase + trim);
    v_drive_befoverlay = Vcmd;
  }

  void tick(float Iraw, float Vbase) {
    uint32_t now = micros();
    if (now - lastTickUs < periodUs) {
      return; // wait until next tick
    }
    lastTickUs = now;

    // Update filtered current
    Ibar = ema(Ibar, Iraw, alpha);
    if (isinf(Iref)) Iref = Ibar;            // first sample
    // Let the "best" baseline drift upward to follow changing conditions
    if (Ibar > Iref) Iref += drift * (Ibar - Iref);
    else             Iref  = Ibar;           // if we see lower current, follow it immediately

    // Settling time after a voltage change
    if (settleLeft > 0) {
      settleLeft--;
      applyCommand(Vbase);
      return;
    }

    bool improved = (Ibar + eps < Iref);

    if (improved) {
      // Accept direction; slightly grow step
      step = min(step * 1.2f, step_max);
      // Advance trim in same direction
      trim += dir * step;
      // Keep command within bounds (relative to Vbase)
      float Vcmd = clampV(Vbase + trim);
      // If clamped, flip and shrink
      if (Vcmd == Vmin || Vcmd == Vmax) {
        trim = Vcmd - Vbase;
        dir  = -dir;
        step = max(step * 0.5f, step_min);
      }
      settleLeft = settleTicks;
      Iref = Ibar; // new local best
      applyCommand(Vbase);
    } else {
      // Backtrack: flip direction & shrink step
      dir  = -dir;
      step = max(step * 0.5f, step_min);
      trim += dir * step;
      // Bound again
      float Vcmd = clampV(Vbase + trim);
      if (Vcmd == Vmin || Vcmd == Vmax) {
        trim = Vcmd - Vbase;
      }
      settleLeft = settleTicks;
      applyCommand(Vbase);
      //Serial.println(motor.voltage_limit);
    }
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

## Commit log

2025-11-21 design for manufacture v1
    [back cover.stl, bearing_cushion (1).stl, flywheel.stl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]
2025-12-01 schematic and pcb
    the schematic is borked due to the export process values are missing, I will upload easyeda files soon but easyeda is messed up today
2025-12-09 ton of changes
    [0_5mmwasher.stl, 0_7mmwasherstepper.stl, 1mmstepperwasher.stl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]
2025-12-09 preliminary bom (only preliminary)
    [BOM for Big Quiet Fan Designed for manufacture version 1.0 alpha.ods]
2025-12-11 bom alpha
    [BOM for Big Quiet Fan Designed for manufacture version 1.0 alpha.ods]
2025-12-23 backup basically
    I probably should not put all this stuff in the repository. I started by trying to make things open but there is a lot of experimenting that produces nearly useless files. I will remove them later af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
    [backcapturething2.stl, backcapturethingcoupler.stl, backcover_tpu95A.3mf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]
2025-12-24 flywheel experiments backup
    [cf_clampeflywheel oneside.stl, dec16shaftcoupler_allfourpartsworksgoodatallspeedstenbolts.step, flywheelhardclamp_petgcf.3mf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]
2026-01-01 updated files
    added grillle, finalized the flywheel/coupler and thickened the primary a bit just in case.
    [bearing_cushion (1).stl, bladeside_coupler.3mf, dec16shaftcouplerdec31_2025.step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]
2026-01-08 bom and minor stuff
    [BOM for Big Quiet Fan Designed for manufacture version 1.0 alpha(1).ods, BOM for Big Quiet Fan Designed for manufacture version 1.0 alpha.ods, flywheelhardclam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]
2026-01-31 intake grille and arduino firmware improvement
    [bearingcushions 72D.3mf, bladesidecollar.stl, bladesideshaftcollar85A.3mf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]
2026-02-03 upload latest driver board firmware
2026-02-25 reorg and upload drawings
    [BOM for Big Quiet Fan Designed for manufacture version 1.0 alpha(1).ods, BOM for Big Quiet Fan Designed for manufacture version 1.0(1).ods, BOM_stepperdrivertr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]
2026-02-25 minor mods
    [BOM_stepperdrivertry4-2stdvr-picocorrected_2026-02-19.csv, PickAndPlace_1-PCB_1-PCB_1-PCB_PCB_stepperdrivertry2-2stdvrpicofixed_2026-02-19.csv]
2026-02-25 more mods
    [BOM for Big Quiet Fan Designed for manufacture version 1.0(1).ods, BOM for Big Quiet Fan Designed for manufacture version 1.0(2).ods]
2026-03-26 new stuff
    [mangledprimarytry1.3mf, mangledprimarytry1.stl, mangledprimarytry2.stl]
2026-04-09 bunch of stuff
    [GRILLE2PRINTABLE.stl, back covertaller.stl, backcapturething2.stl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]
2026-05-13 more stuff
    [Body92.stl, blade 12.stl, bladehubfarside.stl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]
2026-05-19 new arduino program with diag output and adjusted current cutoff
    [secondary_center_thickerforvseries.3mf, thickernewsecondarymiddle1.stl]
2026-06-17 reorg update
    [electronicscoverpetg_0.6_trying to get working3.3mf, motor_mount_regular_PETG_JAYO.3mf, threearmedcouplerallthreepieces_june15_2026.3mf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]
